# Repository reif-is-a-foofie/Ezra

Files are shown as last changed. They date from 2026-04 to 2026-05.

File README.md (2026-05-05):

# Project Ezra

**A screenless, voice-first companion phone in active industrial-design development.**

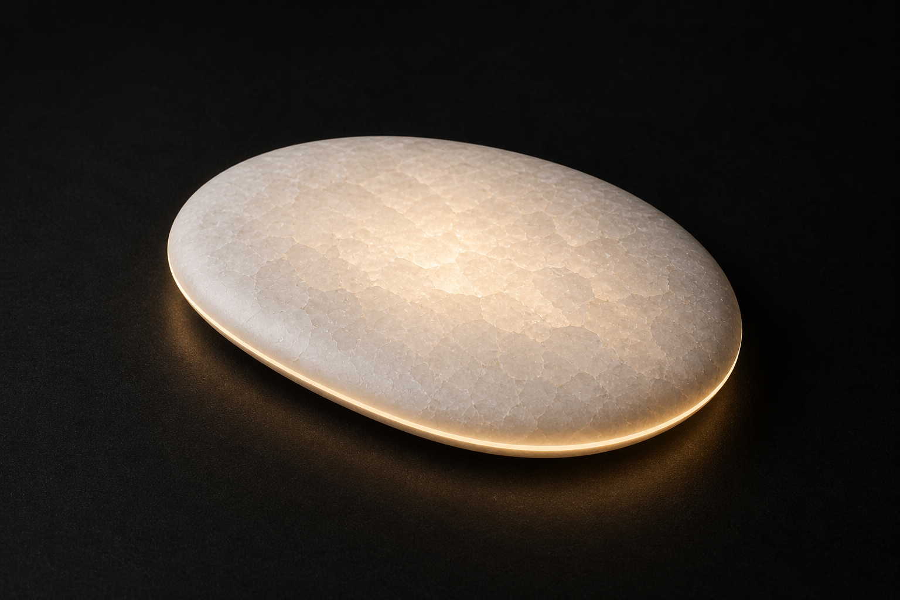
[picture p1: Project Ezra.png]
Project Ezra current render


Ezra is a pocketable AI-native communication and identity device that removes the screen entirely. It does not run apps, show feeds, or create an attention surface. It replaces the smartphone's core jobs - calls, messages, navigation, reminders, authentication, ambient awareness, and emergency utility - with voice, biometric presence, haptics, warmth, and light.

The current design direction is a warm translucent KRION/Corian mineral skip-stone form: calm from the outside, technically dense inside, and built around a clear sensor and packaging plan.

## Brought To You By The Studio

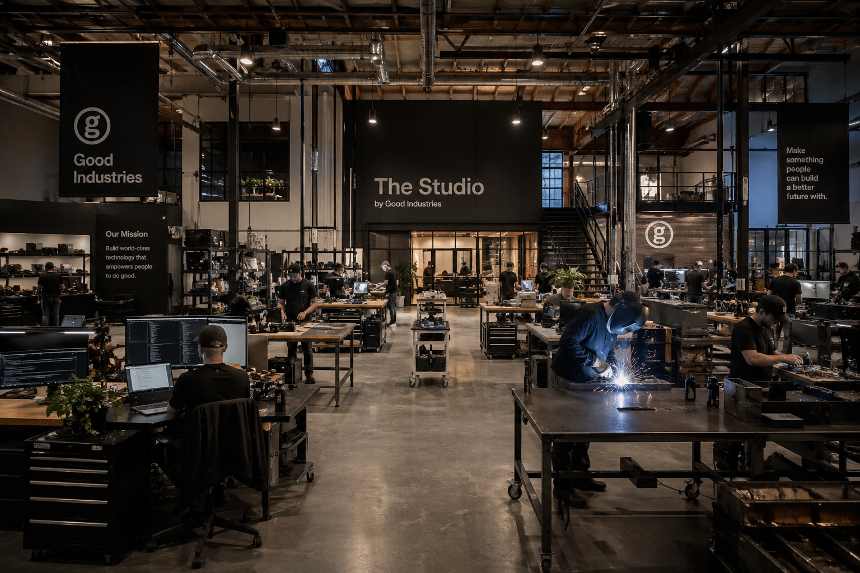
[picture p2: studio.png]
The Studio by Good Industries


Project Ezra comes from The Studio by Good Industries: the hardware, AI, and product workshop inside The Good Project. The Studio is where the concept, industrial design, Blender exploration, Onshape packaging, prototype BOM, and investor demo plan are being pulled into one buildable product direction.

## Current Design Progress

| Area | Current state | Source |
|---|---|---|
| Origin | Brought to you by The Studio, a Good Industries project inside The Good Project | [`studio.png`](studio.png) |
| Hero render | Warm crystalline mineral body with amber internal and perimeter glow | [`Project Ezra.png`](Project%20Ezra.png) |
| Phone plan | Top face, underside, internal stack, sensor map, and BOM callouts | [`project-ezra-phone-plan.svg`](project-ezra-phone-plan.svg) |
| Blender form model | Parametric skip-stone body, material system, glow target, optional feature/package guides | [`ezra_golden_phone/`](ezra_golden_phone/) |
| Blender exports | GLB checked in; OBJ/STL/MTL generated locally for CAD handoff | [`ezra_golden_phone/exports/`](ezra_golden_phone/exports/) |
| Design scenes | Morning guidance, pre-meeting calm, evening wind-down, walk prompt, emotional recovery, and bottom light platform renders | [`ezra_golden_phone/renders/`](ezra_golden_phone/renders/) |
| Onshape package | Product assembly, exploded technical assembly, part studios, and scene assemblies recorded for engineering packaging | [`ezra_golden_phone/ENGINEERING_MANIFEST.md`](ezra_golden_phone/ENGINEERING_MANIFEST.md) |
| Prototype BOM | Procurement and CAD packaging BOM with priorities, estimated pricing, and Onshape reference notes | [`ezra_golden_phone/PROTOTYPE_BUILD_PLAN.md`](ezra_golden_phone/PROTOTYPE_BUILD_PLAN.md) |
| Shape iterations | Twelve silhouette studies used to converge on the skip-stone direction | [`ezra_golden_phone/shape_iterations/`](ezra_golden_phone/shape_iterations/) |
| Earlier nautilus shell | Prior Blender/MCP shell direction and exports retained as design lineage | [`ezra_nautilus/`](ezra_nautilus/) |
| Architecture diagram | System-level hardware/software relationship map | [`system-architecture.svg`](system-architecture.svg) |
| Full spec | Product, hardware, software, identity, privacy, and mechanical packaging spec | [`SPEC.md`](SPEC.md) |
| Hardware spec | Component tables, power budget, PCB architecture, mechanical interface points | [`hardware.md`](hardware.md) |

## Main Phone Plan

Project Ezra phone plan

### Exterior Envelope

| Parameter | Current target |
|---|---:|
| Length | 116 mm |
| Width | 64 mm palm datum, 60 mm visual head taper |
| Thickness | 15 mm crowned center / 5.5 mm visual edge |
| Weight | 165 g prototype target |
| Material | Warm white KRION/Corian mineral composite |
| Form logic | Flattened nautilus / skip-stone superellipse, Lamé exponent `n = 2.5` |
| Crown point | 71.7 mm from trailing end, phi-derived |
| Exterior rule | No screen, camera, visible buttons, screw heads, app surface, or display-like notification region |

The object keeps visual symmetry while hiding tactile asymmetry: a slightly narrower head, fuller tail, thumb-side shelf, rounder finger sweep, rear-biased crown, and underside contact patch that helps orient the device in hand.

### Functional Zones

| Zone | Placement | Purpose |
|---|---|---|
| Sapphire PPG eye | Lower front / palm face | Owner authentication, pickup detection, passive regulation signals |
| Microphone array | Four-point perimeter grid | Wake word, beamforming, calls, voice interface |
| Speaker | Upper face or head edge | Voice response and calls |
| Ambient glow | 0.6 mm perimeter seam or thinned mineral edge | Quiet status, charging, contact presence, no display semantics |
| Thermal presence | Lower rear face | Warmth notification and regulation cue |
| Haptic actuator zone | Palm-biased internal chassis | Tactile language for calls, navigation, alerts, breathing cadence |
| Bottom light platform | Underside | Wide flood, focused flashlight/throw, bedside/emergency light |
| UV-A inspection | Trailing underside | Optional surface inspection demo mode |
| Qi2/MagSafe package | Hidden rear center | Wireless charging alignment without exterior ring language |
| USB-C | Bottom short edge | Prototype service and charging |
| Antenna keepout | Outer perimeter | LTE, WiFi, and Bluetooth clearance away from metal masses |

## Bill of Materials Snapshot

The full BOM is in [`ezra_golden_phone/PROTOTYPE_BUILD_PLAN.md`](ezra_golden_phone/PROTOTYPE_BUILD_PLAN.md). This is the current demo-critical subset driving the Blender and Onshape packaging pass.

| Category | Prototype component | Qty | Priority | Packaging note |
|---|---:|---:|---|---|
| Compute | Raspberry Pi CM4, 4GB RAM, 32GB eMMC, WiFi | 1 | P1 | Main processor volume |
| Compute | CM4 IO board / breakout carrier | 1 | P1 | Prototype carrier, larger than production board |
| Compute | Coral USB Accelerator / Edge TPU | 1 | P2 | Secondary AI compute and thermal allowance |
| Cellular | Quectel EC21 Mini PCIe LTE module | 1 | P1 | SIM access and RF keepout |
| Cellular | LTE adhesive flex antenna | 1 | P2 | Perimeter antenna path |
| Biometric | MAX30102 PPG / SpO2 / HR breakout | 2 | P1 | Underside optical window and isolated light path |
| Biometric | AD5940 EDA board | 1 | P2 | Conductive stress/contact sensing option |
| Biometric | Infineon SLB 9670 TPM 2.0 | 1 | P2 | PPG template and passkey key storage |
| Environmental | Sensirion SEN55 | 1 | P2 | Seam-integrated air path and membrane |
| Environmental | Bosch BMP390 | 1 | P2 | Pressure/temperature vent path |
| Haptic | DRV2605L haptic driver breakout | 2 | P1 | Waveform driver near actuator harness |
| Haptic | 10 mm coin LRA actuators | 4 | P1 | Thumb, palm, left edge, right edge zones |
| Thermal | 20 x 20 mm Peltier TEC element | 1 | P1 | Palm warmth zone with thermal spreader |
| Thermal | DRV8833 dual H-bridge | 1 | P1 | TEC driver and heat/cool control |
| Light | Cree XHP50.3 / COB primary LED | 1 | P1 | Floodlight thermal path and diffuser |
| Light | Ledil ANGIE-S TIR optic | 1 | P2 | Directional torch optic volume |
| Light | Nichia NCSU334A 365 nm UV-A LED | 2 | P1 | Shielded underside inspection emitters |
| Voice | Knowles SPH0645LM4H MEMS mic breakout | 2 | P1 | Hidden mic pores and acoustic channels |
| Voice | MAX98357A I2S amplifier + speaker | 1 | P1 | Speaker cavity and acoustic slit |
| Power | BQ25895 USB-C charger / power path board | 1 | P1 | Charger board, battery path, USB-C route |
| Power | 4000 mAh single-cell LiPo battery | 1 | P1 | Largest prototype internal mass |
| Power | USB-C breakout board | 1 | P2 | Gasketed port |
| Shell | White Corian/KRION shell stock | 1 | P2 | CNC shell and sensor drilling |

## Sensor And Subsystem Specs

### Identity

Ezra uses a MAX30102/MAX30101 PPG sensor behind a 12 mm sapphire optical window. On pickup, the device captures pulse waveform features for owner verification and session continuity. The same sensor family also supports non-medical regulation intelligence such as heart-rate trend, HRV trend, recovery signal, sympathetic arousal, circulation quality, respiratory rhythm trend, and baseline drift.

Security target: PPG template and passkey material stay on device, backed by a TPM/security element. Ezra can act as a FIDO2/WebAuthn authenticator where PPG verification supplies user verification.

### Voice And Calls

The audio stack is a four-microphone MEMS perimeter array, wake-word DSP, speech ASR, LLM/TTS response loop, MAX98357A I2S amplifier, and a 2 W speech-focused speaker. The device is designed for phone calls, voice messages, reminders, and hands-free assistance without visual UI.

### Haptic, Thermal, And Light Language

The non-screen interface uses:

| Channel | Hardware | Example behavior |
|---|---|---|
| Haptic | LRA actuators + DRV2605L | Incoming call, navigation waypoint, breath cadence, urgent alert |
| Thermal | Thin TEC or warming plate | Warmth from designated contact, regulation cue |
| Ambient glow | RGBW/amber perimeter light pipe | Quiet status, charging, presence |
| Utility light | Bottom flood/throw/flood bands | Bedside mode, emergency light, work-surface illumination |
| UV-A | Shielded 365 nm emitters | Inspection demo mode |

### Power And Packaging

The prototype BOM starts with a 4000 mAh LiPo because it is immediately buildable. The product target is a custom 5500-6500 mAh geometry under the crowned shell, with USB-C PD, hidden Qi2/MagSafe-style receiver coil, magnet ring, fuel gauge, PMIC, DC-DC rails, and perimeter antenna keepouts.

## Blender Design Package

The current Blender model is generated from [`ezra_golden_phone/scripts/build_ezra_golden_phone.py`](ezra_golden_phone/scripts/build_ezra_golden_phone.py). The script encodes the live exterior dimensions, crown offset, superellipse body, tactile asymmetry, foot placement, stone material, amber glow, bottom light platform, and optional packaging/feature guides.

Run:

```sh
blender --background --python ezra_golden_phone/scripts/build_ezra_golden_phone.py -- --save-blend --export-all --render-hero
```

Useful review flags:

```sh
--show-features
--show-packaging
```

Current checked-in/generated Blender assets:

| Asset | Purpose |
|---|---|
| [`ezra_golden_phone/ezra_golden_phone.blend`](ezra_golden_phone/ezra_golden_phone.blend) | Blender source scene |
| [`ezra_golden_phone/exports/ezra_golden_phone.glb`](ezra_golden_phone/exports/ezra_golden_phone.glb) | Portable 3D review export |
| [`ezra_golden_phone/exports/ezra_golden_phone.obj`](ezra_golden_phone/exports/ezra_golden_phone.obj) | Mesh export for CAD handoff |
| [`ezra_golden_phone/exports/ezra_golden_phone.stl`](ezra_golden_phone/exports/ezra_golden_phone.stl) | Fabrication/CAD handoff export |
| [`ezra_golden_phone/renders/hero_internal_glow.png`](ezra_golden_phone/renders/hero_internal_glow.png) | Current glow/form hero render |
| [`ezra_golden_phone/renders/bottom_light_platform.png`](ezra_golden_phone/renders/bottom_light_platform.png) | Underside light-platform review |
| [`ezra_golden_phone/renders/morning_guidance_bedside.png`](ezra_golden_phone/renders/morning_guidance_bedside.png) | Morning pickup scene |
| [`ezra_golden_phone/renders/pre_meeting_calm_haptic.png`](ezra_golden_phone/renders/pre_meeting_calm_haptic.png) | Pre-meeting regulation scene |
| [`ezra_golden_phone/renders/evening_wind_down_amber.png`](ezra_golden_phone/renders/evening_wind_down_amber.png) | Evening wind-down scene |
| [`ezra_golden_phone/renders/walk_prompt_subtle_pulse.png`](ezra_golden_phone/renders/walk_prompt_subtle_pulse.png) | Walk prompt scene |
| [`ezra_golden_phone/renders/emotional_recovery_warmth.png`](ezra_golden_phone/renders/emotional_recovery_warmth.png) | Emotional recovery scene |

### Shape Iterations

The checked-in shape studies document the path from simple oval and golden pebble through thinner, fuller, thumb-indexed, and athletic skip-stone variants. They are intentionally shape-only: no sensors, material detailing, glow, or mesh complexity. The recommended direction is the skip-stone family, with the Corian/KRION material, luminous mesh, PPG island, charger package, and scene lighting applied after silhouette selection.

See [`ezra_golden_phone/shape_iterations/README.md`](ezra_golden_phone/shape_iterations/README.md).

### Prior Nautilus Direction

[`ezra_nautilus/`](ezra_nautilus/) keeps the earlier nautilus-shell Blender direction, including the MCP addon, build script, blend source, GLB/OBJ/STL exports, and a turntable frame. It is retained as design lineage and a source of the flattened-nautilus construction logic behind the current skip-stone body.

## System Architecture

Ezra system architecture

## Onshape Engineering Package

The Onshape package is recorded in [`ezra_golden_phone/ENGINEERING_MANIFEST.md`](ezra_golden_phone/ENGINEERING_MANIFEST.md) and [`ezra_golden_phone/PROTOTYPE_BUILD_PLAN.md`](ezra_golden_phone/PROTOTYPE_BUILD_PLAN.md).

Primary document:
`Codex_Diagnostic_Test`

Current assemblies:

| Assembly | Purpose |
|---|---|
| `Ezra_Product_Assembly_v1` | Product-level packaging assembly |
| `Ezra_Exploded_Technical_Assembly_v1` | Exploded assembly for technical review |
| `Ezra_Internal_Packaging_BOM_v1` | BOM-driven internal packaging assembly |
| `Ezra_BOM_Packaging_Placeholders_v1` | Placeholder geometry and imported/vendor references |

Part Studios called out in the manifest:

| Part Studio | Purpose |
|---|---|
| `Top_Shell_A` | KRION/Corian top shell envelope, seam strategy, internal rib/standoff intent |
| `Bottom_Shell_A` | Underside, contact patch logic, sapphire PPG recess |
| `Frame_Internal_Mg` | Magnesium or glass-filled nylon internal chassis envelope |
| `Battery_Main_6000` | 82 x 45 x 9 mm pouch-envelope target |
| `PCB_Main_v1` | Main logic board, AI SoC/NPU, PMIC clusters |
| `Sensor_PPG_Module` | Secondary sensor PCB and PPG optical alignment |
| `Audio_System_Dual` | Voice speaker chamber and directional edge speaker envelope |
| `Light_System_Optics` | COB flood MCPCB and TIR flashlight lens |
| `Haptic_System_LRA` | Actuator envelope and elastomer cradle |
| `Thermal_Warmth_Module` | Graphite spreader and palm warmth zone |
| `Connectivity_Antenna_Zones` | Perimeter antenna keepout envelope |
| `Charging_USB_Qi_Module` | Hidden Qi coil, magnet ring, USB-C strategy |
| `Environmental_Sensors_Vents` | Seam-integrated vent manifold and waterproof membrane intent |

Product scene assemblies already captured for review:

| Scene | Element ID | Intent |
|---|---|---|
| `Ezra_Scene_Morning_Guidance` | `33a3eb97a8d03f4b2b933002` | Bedside pickup, soft glow, low-recovery coaching |
| `Ezra_Scene_PreMeeting_Calm` | `a2336167188af890deb331b7` | Elevated pulse while held, slow haptic breathing cadence |
| `Ezra_Scene_Evening_WindDown` | `262a42c2ed729bab77166748` | Warm amber bedside mode, sleep-window guidance |
| `Ezra_Scene_WalkPrompt` | `806f9729d9de121066534e79` | Midday sedentary pattern, subtle pulse prompt |
| `Ezra_Scene_Emotional_Recovery` | `2e2a42f345d9b77ae6e173cd` | Post-stress regulation, gentle warmth and voice guidance |

## Demo Critical Path

| Moment | Behavior | Hardware dependency |
|---|---|---|
| Hand authentication | Owner recognized from PPG pickup in roughly 4 seconds | MAX30102, TPM, enrollment model |
| Warm contact | Designated contact triggers warmth plus amber haptic pulse | LTE, LRA, TEC, light channel |
| Voice and memory | Spoken query answered from structured personal memory | CM4, mic array, speaker, LLM stack |
| UV sweep | Surface contamination fluoresces under UV-A | UV-A LEDs, filter, baffle |
| Live call | Voice command places a cellular or VoIP call | LTE, audio stack, modem software |

## Repository Map

```text
.
├── README.md
├── Project Ezra.png
├── project-ezra-phone-plan.svg
├── SPEC.md
├── hardware.md
├── firmware.md
├── haptic-language.md
├── ppg-authentication.md
├── prototype-guide.md
├── studio.png
├── system-architecture.svg
├── ezra_golden_phone/
│   ├── BRIEF.md
│   ├── ENGINEERING_MANIFEST.md
│   ├── PROTOTYPE_BUILD_PLAN.md
│   ├── ezra_golden_phone.blend
│   ├── exports/
│   ├── renders/
│   └── scripts/
└── ezra_nautilus/
    ├── BRIEF.md
    ├── ezra_nautilus.blend
    ├── exports/
    ├── renders/
    └── scripts/
```

## Status

| Track | Status |
|---|---|
| Concept and specification | Complete enough for investor/prototype package |
| Industrial design | Active: skip-stone form, glow language, underside light platform |
| Blender shell model | Active and exportable |
| Onshape packaging | Started: product assembly, exploded assembly, part studios, BOM placeholders |
| Prototype BOM | Drafted with P1/P2 priorities and procurement estimates |
| Firmware stack | Scoped |
| PPG authentication | Scoped |
| Voice stack | Scoped |
| Manufacturing partner selection | Pending |

Project Ezra is brought to you by The Studio, a project from Good Industries inside The Good Project.
[thegoodproject.net](https://thegoodproject.net)

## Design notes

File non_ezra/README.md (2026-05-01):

# Non-Ezra Support Material

This folder holds project-adjacent support material that is not part of the Ezra product specification or current skip-stone industrial design source of truth.

Current contents may include:

- `brand-kit/`: Good Industries / studio brand assets.
- `tools/`: local tool/plugin support material, including Onshape MCP references.

Ezra product work should live in root specs or the `ezra_golden_phone/` design folder.

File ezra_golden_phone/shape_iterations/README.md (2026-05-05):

# Ezra Shape Iterations

Shape-only review. No mesh, no glow, no sensors, no material detailing.

| Variant | Render | Notes |
|---|---|---|
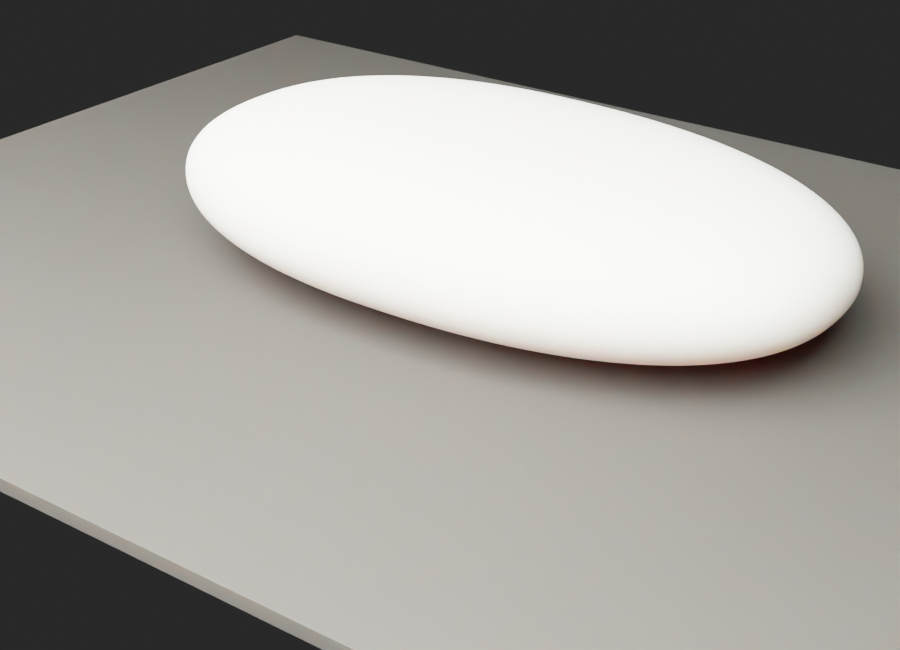
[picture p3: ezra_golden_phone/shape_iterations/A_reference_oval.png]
| A - Reference Oval |  | Closest to the hand stone: simple oval, felt asymmetry, least gadget-like. |
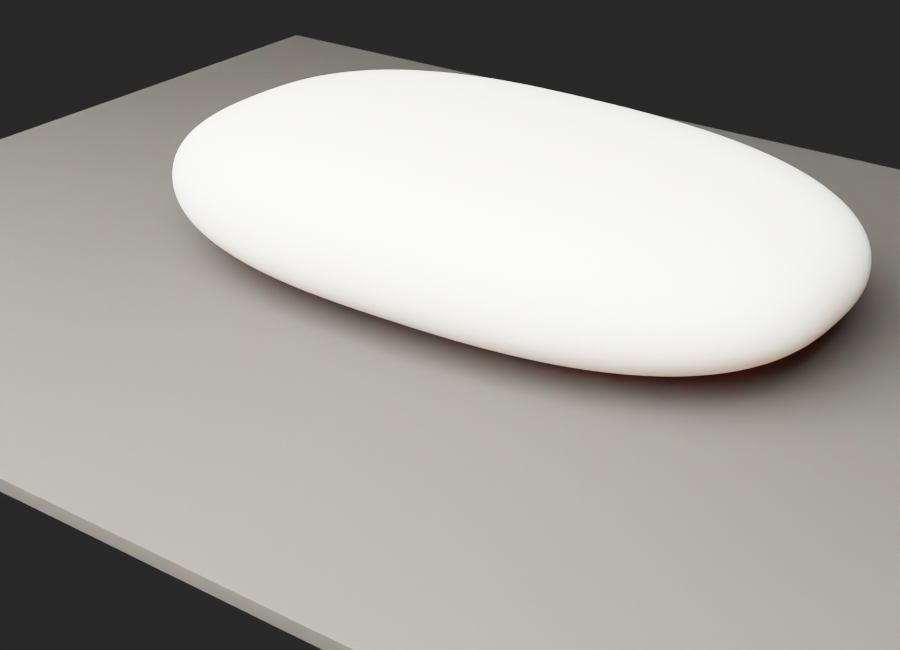
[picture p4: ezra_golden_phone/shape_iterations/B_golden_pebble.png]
| B - Golden Pebble |  | Current spec translated into a more natural pebble, still phone/pocket scaled. |
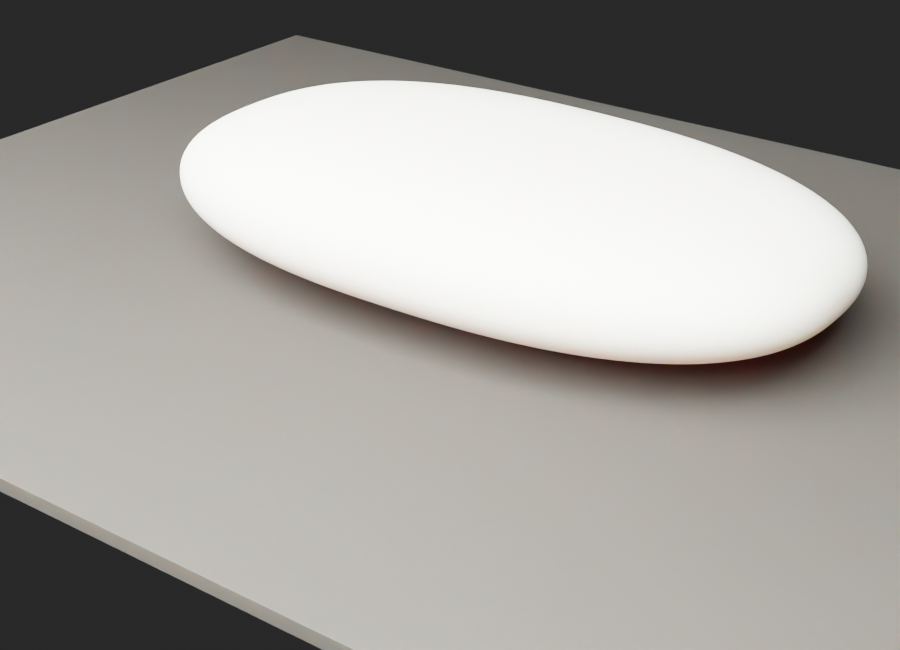
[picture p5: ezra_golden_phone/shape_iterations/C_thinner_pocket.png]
| C - Thinner Pocket |  | More pocketable and less object-heavy; may lose heirloom density. |
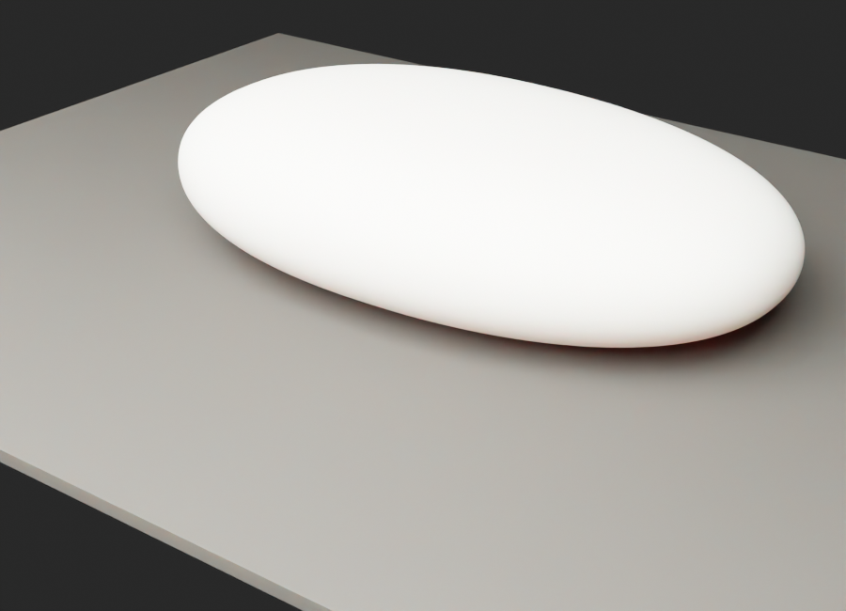
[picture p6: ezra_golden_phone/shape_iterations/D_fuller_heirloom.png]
| D - Fuller Heirloom |  | Most stone-like mass and warmth; strongest hand presence. |
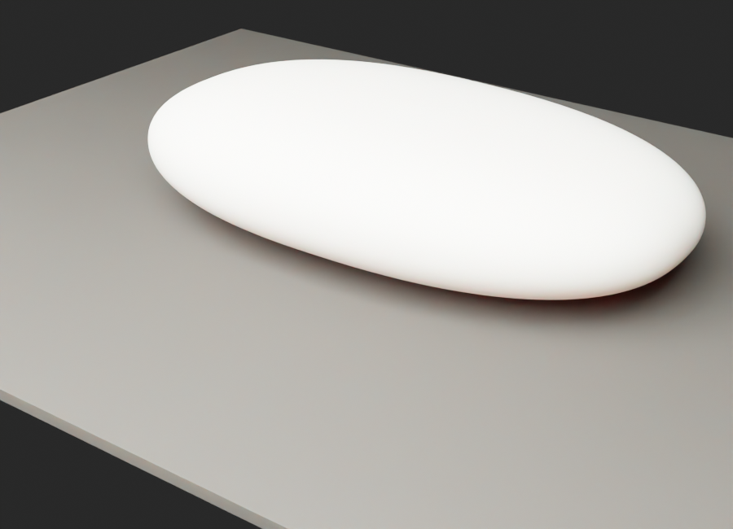
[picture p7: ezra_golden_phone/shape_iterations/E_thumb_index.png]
| E - Thumb Index |  | Same visual calm, stronger one-side flattening for pocket orientation. |
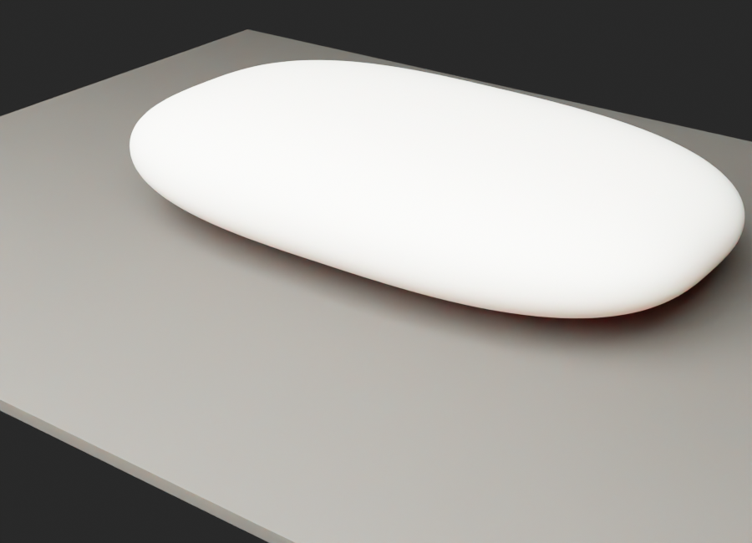
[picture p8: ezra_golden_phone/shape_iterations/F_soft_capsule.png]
| F - Soft Capsule |  | More phone-compatible silhouette; safer for chargers but less natural. |
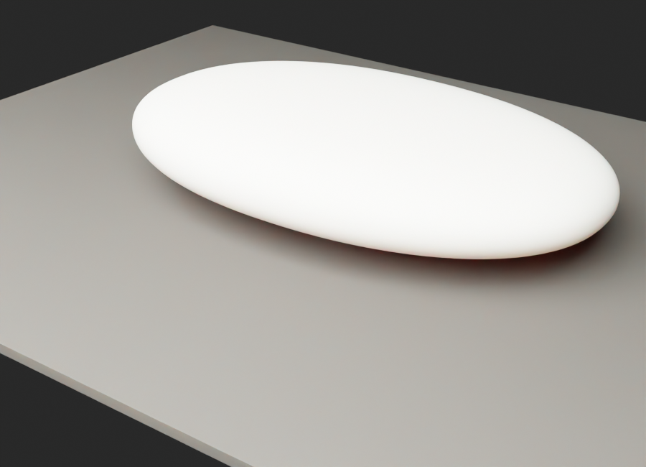
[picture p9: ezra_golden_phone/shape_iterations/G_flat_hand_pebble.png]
| G - Flat Hand Pebble |  | Closest to the grey reference: broad horizontal palm stone, low dome, soft lens edge. |
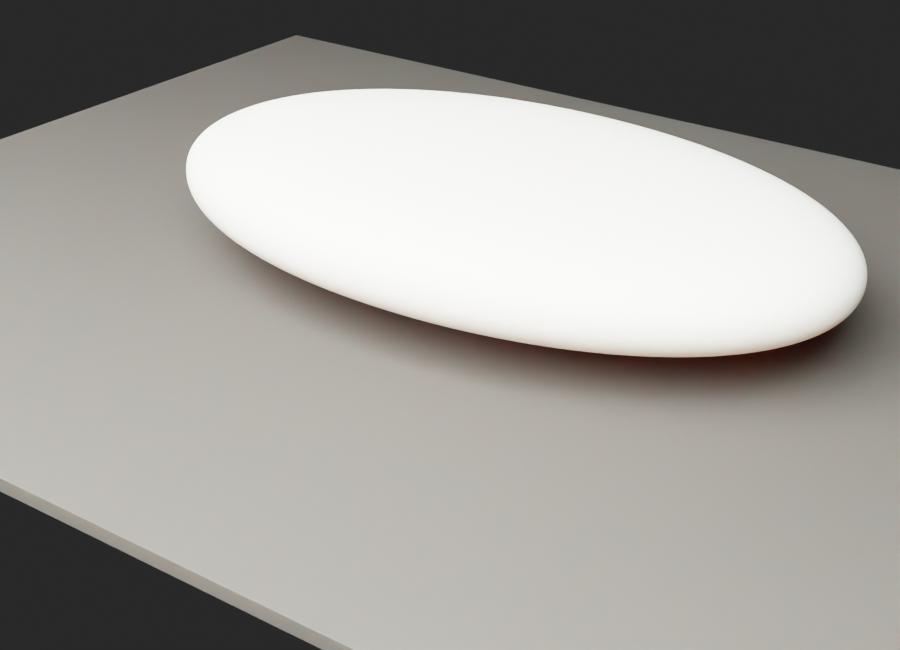
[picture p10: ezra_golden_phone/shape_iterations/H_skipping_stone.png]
| H - Skipping Stone |  | Thinnest and calmest; very pocketable, but internal packaging becomes harder. |
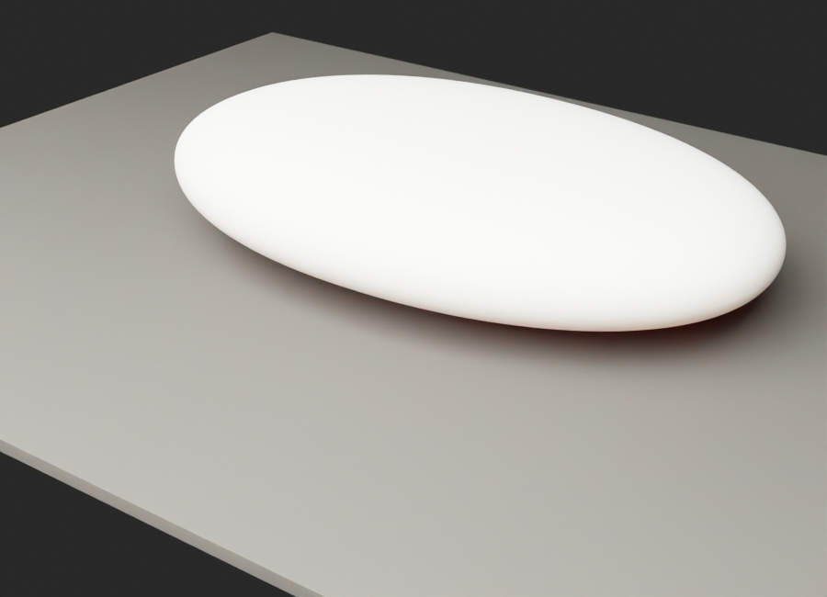
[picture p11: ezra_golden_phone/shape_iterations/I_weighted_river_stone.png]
| I - Weighted River Stone |  | Reference-like broad face with more belly for battery and hand warmth. |
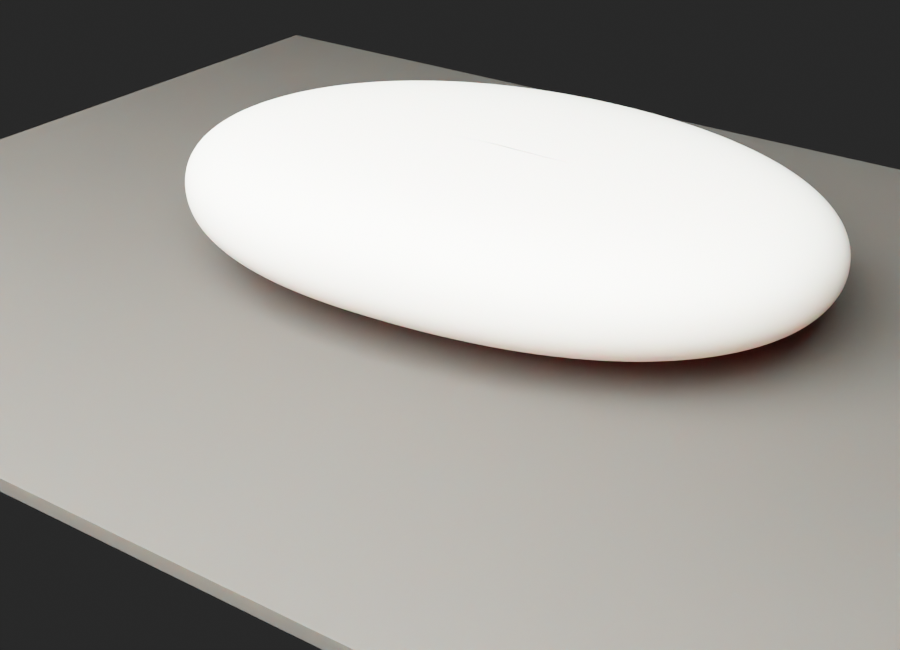
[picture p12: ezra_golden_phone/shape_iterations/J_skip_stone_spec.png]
| J - Skip Stone Spec |  | Direct translation of the new brief: 103 x 75 x 17.5 mm, broad and thin with lens taper. |
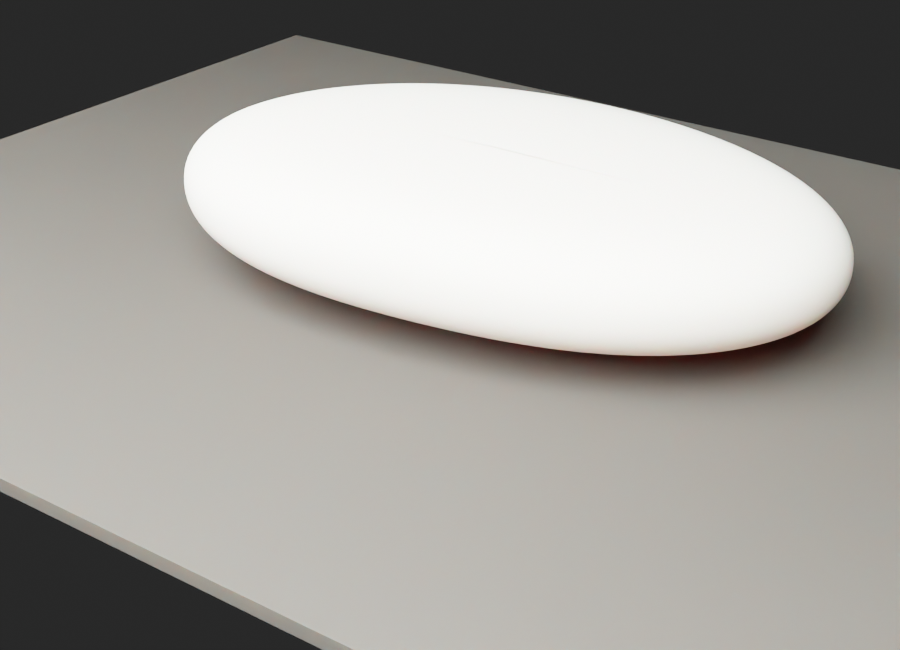
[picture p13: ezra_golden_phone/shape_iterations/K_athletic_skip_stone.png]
| K - Athletic Skip Stone |  | Faster leading end and stronger diagonal energy; more capable/tool-like. |
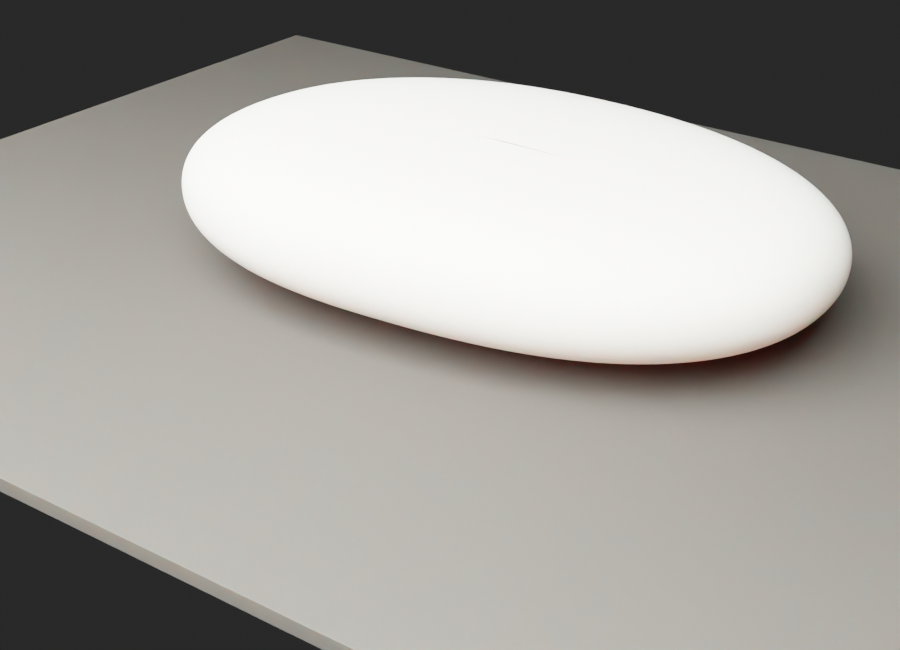
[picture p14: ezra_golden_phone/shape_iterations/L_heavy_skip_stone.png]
| L - Heavy Skip Stone |  | Keeps the skip-stone plan but restores internal volume for battery/speakers. |

Recommendation: choose silhouette first, then apply Corian/KRION material, luminous mesh, PPG island, charger packaging, and scene lighting to one selected direction.

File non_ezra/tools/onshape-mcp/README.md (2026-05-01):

# Onshape MCP Server

Enhanced Model Context Protocol (MCP) server for programmatic CAD modeling with Onshape.

## Features

This MCP server provides comprehensive programmatic access to Onshape's REST API, enabling:

### Core Capabilities (45 tools)

- **Document Discovery** - Search and list projects, find Part Studios, navigate workspaces
- **Parametric Sketches** - Rectangles, circles, lines, and arcs on standard planes
- **Feature Management** - Extrude, revolve, thicken, fillet, chamfer, boolean, and pattern features
- **Assembly Management** - Create assemblies, add instances, position parts, create mates (fastened, slider, revolute, cylindrical)
- **Assembly Analysis** - Interference checking, position verification, face coordinate systems, body details
- **Variable Tables** - Read and write Onshape variable tables for parametric designs
- **FeatureScript** - Evaluate FeatureScript expressions, get bounding boxes
- **Export** - Export Part Studios and Assemblies to STL, STEP, PARASOLID, GLTF, OBJ
- **Part Studio Management** - Create and manage Part Studios programmatically

## Installation

### Prerequisites

- Python 3.10 or higher
- Onshape account with API access
- Onshape API keys (access key and secret key)

### Setup

1. Clone the repository:
```bash
git clone https://github.com/hedless/onshape-mcp.git
cd onshape-mcp
```

2. Create a virtual environment:
```bash
python -m venv venv
source venv/bin/activate  # On Windows: venv\Scripts\activate
```

3. Install dependencies:
```bash
pip install -e .
```

4. Set up environment variables:
```bash
export ONSHAPE_ACCESS_KEY="your_access_key"
export ONSHAPE_SECRET_KEY="your_secret_key"
```

Or create a `.env` file:
```
ONSHAPE_ACCESS_KEY=your_access_key
ONSHAPE_SECRET_KEY=your_secret_key
```

## Getting Onshape API Keys

1. Go to [Onshape Developer Portal](https://dev-portal.onshape.com/)
2. Sign in with your Onshape account
3. Create a new API key
4. Copy the Access Key and Secret Key

## Usage

### Running the Server

```bash
onshape-mcp
```

Or directly with Python:
```bash
python -m onshape_mcp.server
```

### Configuring with Claude Code

Add to your `~/.claude/mcp.json`:

```json
{
  "mcpServers": {
    "onshape": {
      "command": "/absolute/path/to/onshape-mcp/venv/bin/python",
      "args": ["-m", "onshape_mcp.server"],
      "env": {
        "ONSHAPE_ACCESS_KEY": "your_access_key_here",
        "ONSHAPE_SECRET_KEY": "your_secret_key_here"
      }
    }
  }
}
```

**Important Notes:**
- Use the **absolute path** to your virtual environment's Python executable
- Find your path: `cd onshape-mcp && pwd` to get the directory path
- On Windows: Use `C:/path/to/onshape-mcp/venv/Scripts/python.exe`
- Replace the API keys with your actual keys from [Onshape Developer Portal](https://dev-portal.onshape.com/)
- **Restart Claude Code** after editing `mcp.json`

**Verify it works:**
Ask Claude Code: "Can you list my Onshape documents?"

For complete setup instructions, see [docs/QUICK_START.md](docs/QUICK_START.md).

## Available Tools

### Document & Navigation Tools

| Tool | Description |
|---|---|
| `list_documents` | List documents with filtering and sorting |
| `search_documents` | Search documents by name or description |
| `get_document` | Get detailed document information |
| `get_document_summary` | Get comprehensive summary with workspaces and elements |
| `find_part_studios` | Find Part Studios with optional name filtering |
| `get_elements` | Get all elements (Part Studios, Assemblies, BOMs) in a workspace |
| `get_parts` | Get all parts from a Part Studio |
| `create_document` | Create a new Onshape document |
| `create_part_studio` | Create a new Part Studio in a document |

### Assembly Tools

| Tool | Description |
|---|---|
| `create_assembly` | Create a new Assembly in a document |
| `add_assembly_instance` | Add a part or sub-assembly instance to an assembly |
| `get_assembly` | Get assembly structure with instances and occurrences |
| `transform_instance` | Apply a relative transform (inches/degrees). Fails on fixed instances. |
| `set_instance_position` | Set absolute position (resets rotation). Fails on fixed instances. |
| `align_instance_to_face` | Align one instance flush against a face of another |
| `create_mate_connector` | Create an explicit mate connector on a face with offsets |
| `create_fastened_mate` | Create a rigid (fastened) mate between two instances |
| `create_slider_mate` | Create a linear motion mate. First instance slides relative to second. |
| `create_revolute_mate` | Create a rotational mate. First instance rotates relative to second. |
| `create_cylindrical_mate` | Create a slide+rotate mate. First instance moves relative to second. |
| `delete_feature` | Delete a feature (mate, mate connector, etc.) from an assembly or Part Studio |

### Assembly Analysis Tools

| Tool | Description |
|---|---|
| `get_assembly_positions` | Get positions, sizes, and bounds of all instances (in inches) |
| `get_assembly_features` | Get all features with their state (OK/ERROR/SUPPRESSED) |
| `get_body_details` | Get face IDs, surface types, normals, and origins for all parts |
| `get_face_coordinate_system` | Query the outward-facing coordinate system for a specific face |
| `check_assembly_interference` | Check for overlapping/interfering parts using bounding box detection |

### Sketch Tools

| Tool | Description |
|---|---|
| `create_sketch_rectangle` | Rectangle with optional variable references for width/height |
| `create_sketch_circle` | Circle with center point and radius |
| `create_sketch_line` | Line from start point to end point |
| `create_sketch_arc` | Arc with center, radius, start angle, and end angle |

All sketch tools support `plane` (Front/Top/Right) and `name` parameters. Dimensions are in inches.

### Feature Tools

| Tool | Description |
|---|---|
| `create_extrude` | Extrude a sketch with depth, optional variable reference, and operation type |
| `create_thicken` | Thicken a sketch into a solid with optional midplane/opposite direction |
| `create_revolve` | Revolve a sketch around an axis (X/Y/Z) with angle and operation type |
| `create_fillet` | Round edges by edge IDs with radius (supports variable references) |
| `create_chamfer` | Bevel edges by edge IDs with distance (supports variable references) |
| `create_linear_pattern` | Repeat features along an axis (X/Y/Z) with distance and count |
| `create_circular_pattern` | Repeat features around an axis with count and angle spread |
| `create_boolean` | Union, subtract, or intersect bodies by deterministic IDs |

### Variable & Feature Tools

| Tool | Description |
|---|---|
| `get_variables` | Get all variables from a Part Studio variable table |
| `set_variable` | Set or update a variable (e.g., `"0.75 in"`) |
| `get_features` | Get all features from a Part Studio |

### FeatureScript Tools

| Tool | Description |
|---|---|
| `eval_featurescript` | Evaluate a FeatureScript lambda expression (read-only) |
| `get_bounding_box` | Get the tight bounding box of all parts in a Part Studio |

### Export Tools

| Tool | Description |
|---|---|
| `export_part_studio` | Export to STL, STEP, PARASOLID, GLTF, or OBJ (optional `partId` filter) |
| `export_assembly` | Export to STL, STEP, or GLTF |

## Architecture

```
onshape_mcp/
├── api/
│   ├── client.py         # HTTP client with HMAC authentication
│   ├── documents.py      # Document discovery & navigation
│   ├── partstudio.py     # Part Studio management
│   ├── variables.py      # Variable table management
│   ├── assemblies.py     # Assembly lifecycle, mates & features
│   ├── export.py         # Part Studio & Assembly export
│   └── featurescript.py  # FeatureScript evaluation
├── builders/
│   ├── sketch.py         # Sketch builder (rectangle, circle, line, arc, polygon)
│   ├── extrude.py        # Extrude feature builder
│   ├── revolve.py        # Revolve feature builder
│   ├── fillet.py         # Fillet feature builder
│   ├── chamfer.py        # Chamfer feature builder
│   ├── boolean.py        # Boolean operations (union, subtract, intersect)
│   ├── pattern.py        # Linear & circular pattern builders
│   ├── mate.py           # Mate connector & mate builders (face-based)
│   └── thicken.py        # Thicken feature builder
├── analysis/
│   ├── interference.py   # Bounding-box interference detection
│   ├── positioning.py    # Instance position queries & alignment
│   └── face_cs.py        # Face coordinate system queries
├── tools/
│   └── __init__.py       # MCP tool definitions
└── server.py             # Main MCP server (45 tools)
```

## Examples

### Example 1: Finding and Working on a Project

```python
# Search for your project
documents = await search_documents(query="robot arm", limit=5)

# Get the first matching document
doc_id = documents[0].id

# Get comprehensive summary
summary = await get_document_summary(doc_id)

# Find Part Studios in main workspace
workspace_id = summary['workspaces'][0].id
part_studios = await find_part_studios(doc_id, workspace_id, namePattern="base")

# Now work with the Part Studio
elem_id = part_studios[0].id
```

### Example 2: Creating a Parametric Cabinet

```python
# Set variables
await set_variable(doc_id, ws_id, elem_id, "width", "39.5 in")
await set_variable(doc_id, ws_id, elem_id, "depth", "16 in")
await set_variable(doc_id, ws_id, elem_id, "height", "67.125 in")
await set_variable(doc_id, ws_id, elem_id, "wall_thickness", "0.75 in")

# Create side panel sketch
await create_sketch_rectangle(
    doc_id, ws_id, elem_id,
    name="Side Panel",
    plane="Front",
    corner1=[0, 0],
    corner2=[16, 67.125],
    variableWidth="depth",
    variableHeight="height"
)

# Extrude to create side
await create_extrude(
    doc_id, ws_id, elem_id,
    name="Side Extrude",
    sketchFeatureId="<sketch_id>",
    depth=0.75,
    variableDepth="wall_thickness"
)
```

## Development

### Running Tests

The project has comprehensive test coverage with **471 unit tests**.

```bash
# Run all tests
pytest

# Run with coverage
pytest --cov

# Run specific module tests
pytest tests/api/test_documents.py -v

# Use make commands
make test
make test-cov
make coverage-html
```

For detailed testing documentation, see [docs/TESTING.md](docs/TESTING.md).

### Code Formatting

```bash
ruff format .
ruff check .
```

## Documentation

### Getting Started
- **[docs/QUICK_START.md](docs/QUICK_START.md)** - Quick start guide for Claude Code users
- **[docs/DEV_SETUP.md](docs/DEV_SETUP.md)** - Development environment setup with SSE mode and debugging

### Development & Testing
- **[docs/TESTING.md](docs/TESTING.md)** - Testing guide and best practices
- **[docs/TEST_SUMMARY.md](docs/TEST_SUMMARY.md)** - Test suite overview
- **[docs/FEATURE_SUMMARY.md](docs/FEATURE_SUMMARY.md)** - Implementation details and statistics

### API & Implementation
- **[docs/ONSHAPE_API_IMPROVEMENTS.md](docs/ONSHAPE_API_IMPROVEMENTS.md)** - API format fixes and BTMSketch-151 implementation
- **[docs/SKETCH_PLANE_REFERENCE_GUIDE.md](docs/SKETCH_PLANE_REFERENCE_GUIDE.md)** - Advanced: Geometry-referenced sketch planes
- **[docs/NEXT_STEPS_GEOMETRY_REFERENCES.md](docs/NEXT_STEPS_GEOMETRY_REFERENCES.md)** - Roadmap for geometry reference implementation
- **[docs/DOCUMENT_DISCOVERY.md](docs/DOCUMENT_DISCOVERY.md)** - Complete guide to document discovery features
- **[docs/PARTS_ASSEMBLY_TOOLS.md](docs/PARTS_ASSEMBLY_TOOLS.md)** - Parts and assembly tool documentation

### Project Analysis & Research
- **[docs/CARPENTRY_PRINCIPLES_FOR_CAD.md](docs/CARPENTRY_PRINCIPLES_FOR_CAD.md)** - How to think like a carpenter in CAD
- **[docs/LEARNING_SUMMARY.md](docs/LEARNING_SUMMARY.md)** - Summary of side panel analysis and learnings
- **[docs/DISPLAY_CABINETS_ANALYSIS_SUMMARY.md](docs/DISPLAY_CABINETS_ANALYSIS_SUMMARY.md)** - Analysis of display cabinets project
- **[docs/AGENT_CREATION_GUIDE.md](docs/AGENT_CREATION_GUIDE.md)** - Guide for creating CAD agents
- **[docs/CREATING_CAD_EXPERT_AGENT.md](docs/CREATING_CAD_EXPERT_AGENT.md)** - Creating specialized CAD expert agents

### Knowledge Base & Examples

- **[knowledge_base/assembly_workflow_guide.md](knowledge_base/assembly_workflow_guide.md)** - Comprehensive assembly methodology (positioning, mates, solver behavior)
- **[examples/cabinet_assembly.md](examples/cabinet_assembly.md)** - Complete worked example: cabinet with sliding drawers
- **[knowledge_base/](knowledge_base/)** - Onshape feature examples and research

## Roadmap

### Current Status

- Document discovery and navigation (10 tools)
- Sketch creation with rectangles, circles, lines, and arcs
- Feature tools: extrude, revolve, thicken, fillet, chamfer, boolean, patterns
- Full assembly management: fastened, slider, revolute, and cylindrical mates with face-based mate connectors
- Assembly analysis: interference checking, position verification, face coordinate systems
- Variable table management
- FeatureScript evaluation and bounding box queries
- Export to STL, STEP, PARASOLID, GLTF, OBJ
- 471 comprehensive unit tests
- Live-tested on multi-part assemblies (25-instance cabinet with 66 features)

### In Research

- **Geometry-referenced sketch planes** - Create sketches on faces from existing features (see [docs/SKETCH_PLANE_REFERENCE_GUIDE.md](docs/SKETCH_PLANE_REFERENCE_GUIDE.md))
- Query API investigation - How to programmatically reference geometry
- Entity ID mapping - Understanding Onshape's internal ID system

### Near-Term Priorities

- [ ] Implement `create_sketch_on_geometry()` for carpentry-correct cabinet assembly
- [ ] Sketch constraints (coincident, parallel, tangent, etc.)
- [ ] Pocket cuts and profiles for joinery (dados, rabbets)

### Long-Term Goals

- [ ] Drawing creation
- [ ] Bill of Materials (BOM) generation
- [ ] Advanced constraints and relations
- [ ] Configuration parameter support

### Woodworking-Specific Features

- [ ] Joinery library (dado, rabbet, mortise & tenon, dovetail)
- [ ] Standard hardware patterns (shelf pins, drawer slides)
- [ ] Cut list generation
- [ ] Material optimization (sheet layout)
- [ ] Assembly instructions generation

## Contributing

Contributions are welcome! Please feel free to submit a Pull Request.

## License

MIT License

## Acknowledgments

- Inspired by [OnPy](https://github.com/kyle-tennison/onpy)
- Built on the [Model Context Protocol](https://modelcontextprotocol.io/)
- Onshape API documentation: https://onshape-public.github.io/docs/

## Support

For issues and questions:
- GitHub Issues: https://github.com/hedless/onshape-mcp/issues
- Onshape API Forum: https://forum.onshape.com/

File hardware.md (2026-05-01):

# Ezra — Hardware Specification

**Version:** 0.3  
**Stage:** Pre-prototype (Investor Demo Build)

---

## Component Selection Table

### Compute

| Component | Part | Manufacturer | Notes |
|---|---|---|---|
| System on Chip | CM4 (4GB RAM / 32GB eMMC) | Raspberry Pi Foundation | Prototype only; production target: custom ARM SoC |
| Security Element | SLB 9670 TPM 2.0 | Infineon | PPG template and FIDO2 key storage |
| I/O Expander | MCP23017 | Microchip | GPIO expansion for button inputs and LED control |

### Cellular & Wireless

| Component | Part | Manufacturer | Notes |
|---|---|---|---|
| LTE Modem | EC25-A Mini PCIe | Quectel | Cat 4 LTE, North America bands |
| Antenna | FXP73 flex LTE | Taoglas | Embedded in chassis perimeter |
| WiFi / Bluetooth | Integrated | RPi Foundation | CM4 onboard 802.11ac + BT 5.0 |
| SIM Slot | Nano SIM + eSIM | — | Dual SIM support |

### Audio

| Component | Part | Manufacturer | Interface | Notes |
|---|---|---|---|---|
| Speaker | GF0401 (2W, 4Ω, 40mm) | Dayton Audio | Analog | Tuned for 200Hz–8kHz voice |
| Amplifier | MAX98357A | Maxim | I2S | 3.2W Class D, filterless |
| MEMS Mic (×4) | SPH0645LM4H | Knowles | I2S | Golden-rectangle perimeter array, phi-derived spacing |
| DSP / Wake Word | TrulyHandsfree SDK | Sensory | SPI | Wake word "Ezra," always-on < 10mW |

### Biometric / Identity

| Component | Part | Manufacturer | Interface | Notes |
|---|---|---|---|---|
| PPG Sensor | MAX30102 | Maxim/Analog Devices | I2C | Red 660nm + IR 880nm |
| Optical Window | Sapphire disc, 12mm × 1.5mm | Industrial optics supplier | — | < 2% loss at sensor wavelengths |
| Optical Adhesive | NOA61 UV adhesive | Norland | — | Window to sensor bonding |

### Passive Regulation Signals

The PPG subsystem is a continuous relationship sensor, not just an unlock mechanism. It should sample opportunistically on pickup and during natural palm contact, then feed local trend models for heart rate, HRV, recovery state, stress-load trend, sympathetic arousal, cold-hand/circulation state, respiratory rhythm trend, and baseline drift. This is product guidance data, not diagnostic data.

Regulatory constraint: do not claim medical diagnosis, disease detection, treatment, or clinical accuracy unless Ezra enters a formal regulated medical pathway. Default positioning is pattern intelligence and personal regulation.

### Haptic

| Component | Part | Manufacturer | Interface | Notes |
|---|---|---|---|---|
| Actuator | L5 LRA | Lofelt | — | ±3g peak force, 50–300Hz |
| Driver | DRV2605L | Texas Instruments | I2C | Arbitrary waveform RAM |
| Isolation | Sorbothane 40 duro | Sorbothane | — | Actuator mount isolation |

### Thermal (Warmth)

| Component | Part | Manufacturer | Notes |
|---|---|---|---|
| Thermoelectric element | Thin thermal module / resistive warming plate | TBD | Production target for 21mm crowned body with 8mm edge thickness |
| Demo Peltier Element | TEC1-12706 | Generic | 40×40mm, 6A max, 51W; benchtop/investor demo only |
| MOSFET Driver | IRL3803 | Vishay | PWM control via CM4 GPIO |
| Heat Spreader | 1mm copper sheet, 50×40mm | McMaster-Carr | Hot side to chassis mass |
| Thermal Interface | Fujipoly XR-m (3 W/mK) | Fujipoly | Element to spreader |

### Illumination

| Component | Part | Manufacturer | Notes |
|---|---|---|---|
| COB LED Array | BXRE-27G1000-C-73 (1,200 lm) | Bridgelux | Main flood/beam element |
| TIR Optic | TIR-T-H-10 (10° beam) | LEDiL | 60m beam throw |
| LED Driver | AL8861 | Diodes Inc. | Constant current, PWM dimming |
| Ambient Ring | SK6812 RGBW, 5mm, ×8 | Worldsemi | Notification color language |

### Power

| Component | Part | Manufacturer | Notes |
|---|---|---|---|
| Battery | Custom Li-ion pouch, target 5,500–6,500mAh equivalent geometry | TBD | Largest central internal component; conformal or stacked pouch layout under crowned shell |
| Charging IC | BQ25895 | Texas Instruments | USB-C PD, 18W input |
| Wireless charging receiver | Qi2/MagSafe-compatible receiver module | TBD | Hidden centered rear coil; validate certification path with WPC |
| Magnetic alignment ring | N52 magnet ring array | TBD | Hidden under rear shell, sized for common phone magnetic charger puck alignment |
| USB-C Connector | HRO TYPE-C-31-M-17 | HRO | IP54 rated |
| Fuel Gauge | MAX17048 | Maxim | 1% accuracy SoC estimation |
| DC-DC (5V rail) | TPS62133 | Texas Instruments | CM4 power supply |
| DC-DC (3.3V rail) | AP2112K-3.3 | Diodes Inc. | Sensor power rail |

---

## Power Budget (Estimated)

| Subsystem | Active (mA @ 3.7V) | Standby (mA) |
|---|---|---|
| CM4 (idle) | 400 | 80 |
| CM4 (voice processing) | 900 | — |
| LTE Modem (connected) | 350 | 15 |
| Audio (playback) | 180 | 2 |
| PPG sensor (active) | 5 | 0.7 |
| LRA (active) | 200 | 0 |
| Peltier (active, 50% PWM) | 3,000 | 0 |
| COB LED (max) | 1,000 | 0 |
| Misc (MCUs, sensors) | 30 | 8 |

**Typical use (voice + calls, no warmth/LED):** ~1,800mA average → 6,000mAh / 1,800mA ≈ ~3.3 hours of active-heavy use  
**Standby (LTE connected, PPG monitoring):** ~110mA → 6,000mAh / 110mA ≈ ~54 hours

---

## Thermal Constraints

The benchtop TEC1-12706 draws up to 22W (6A × 3.7V) at full duty cycle and is too bulky for the phone-scale enclosure. Production hardware needs a thin thermal module or resistive warming plate sized for burst warmth notifications (3–10 seconds), coupled to the palm-side shell through a graphite spreader. The chassis and mineral shell act as thermal reservoirs.

**Design constraint:** Limit Peltier duty cycle to 30-second maximum per activation. Software-enforced cooldown of 60 seconds between activations to prevent thermal accumulation.

---

## PCB Architecture

The device uses three PCBs:

1. **Main board:** CM4 carrier, LTE modem, power management, USB-C, battery connectors
2. **Sensor board:** MAX30102, DRV2605L, MCP23017, MAX17048, ambient LED ring
3. **Audio board:** MEMS mic array, MAX98357A, speaker connector

Boards connect via FFC (flat flexible cable) with ZIF connectors. This allows sensor and audio boards to be positioned independently of the main board geometry.

---

## Mechanical Interface Points

| Feature | Location | Tolerance |
|---|---|---|
| Speaker aperture | Upper face center | ±0.3mm |
| Sensor window | Lower face center | ±0.1mm (optical alignment critical) |
| Qi receiver coil | Rear center, hidden behind shell | ±0.5mm |
| Magnetic alignment ring | Rear center around coil, hidden behind shell | ±0.5mm |
| USB-C port | Lower edge | ±0.2mm |
| Internal glow / ambient light pipe | Perimeter groove or thinned mineral window | ±0.5mm |
| Peltier contact zone | Lower rear face | ±1mm |
| Battery access (service) | None (sealed) | — |

## Mechanical Envelope

| Parameter | Target |
|---|---|
| Length | 108mm |
| Tail width | 66mm |
| Head width | 63mm |
| Center thickness | 21mm |
| Edge thickness | 8mm |
| Top shell wall | 3.2mm |
| Bottom shell wall | 2.8mm |
| Mass target | 210g |

The exterior must carry subtle tactile asymmetry: narrower head for flashlight/directional speaker/mic orientation, fuller tail for battery and biometric mass, a shallower thumb-side sweep, rounder finger-side squeeze contour, rearward crown offset of roughly 5mm, and a biased underside contact patch. The asymmetry should be felt more than seen.

---

*Hardware spec current as of April 2026. Prototype build may substitute components based on availability.*

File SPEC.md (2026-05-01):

# Ezra — Full Product Specification

**Version:** 0.4 (Pre-prototype)  
**Status:** Specification phase  
**Owner:** Good Industries / The Good Project

---

## 1. Physical Form Factor

### 1.1 Dimensions & Weight

| Parameter | Target |
|---|---|
| Length | 116 mm |
| Width | 64 mm palm datum, with subtly narrower leading/head end |
| Depth | 15 mm crowned center / 5.5 mm visual edge |
| Top shell wall | TBD after shell split; target 3.0-3.5 mm |
| Bottom shell wall | 2.5 mm at light-diffusion zones / 3.5 mm perimeter target |
| Weight | 165g prototype target |
| Form | Flattened nautilus / skip-stone profile with hidden tactile asymmetry |

The governing palm datum is the 64mm short axis. The current skip-stone body is 116mm long, giving A/B = 1.8125. This is intentionally longer than pure φ because the device needs pocket reach, bottom flood-light real estate, and a more athletic skipping-stone read. The form remains φ-influenced through crown placement, foot geometry, haptic placement, seam behavior, and construction logic.

The industrial design target is a translucent warm-white mineral skip stone: longer and thinner than expected, shallow crowned top face, aggressively tapered edges, and no visible screen, camera, buttons, screws, or top markings. The object should feel like a flattened nautilus shell worn into a river stone, not a phone slab or hockey puck.

Ezra uses tactile asymmetry hidden inside visual symmetry. The leading/head end is slightly narrower and faster. The trailing/tail end is calmer and slightly fuller. The right-hand thumb side has a subtle concavity/shelf, while the opposite side remains a smooth finger sweep. The crown peak is φ-derived at 71.7mm from the trailing end, 13.7mm ahead of true center.

Sacred-geometry construction rules:
- **φ:** 1.6180339887.
- **Palm datum:** B = 64mm.
- **Long axis:** A = 116mm.
- **Superellipse:** Lamé curve, n = 2.5.
- **Crown point:** A/φ = 71.7mm from trailing end.
- **Feet:** golden gnomon triangle at (43, 0), (-20, -20), (-20, +20) mm.
- **Foot triangle:** 40mm base, 66.1mm legs, apex angle 35.2°, visually approximating the 36°/72°/72° golden gnomon.
- **Fibonacci spiral:** construction guide only. The top should feel derived from a flattened nautilus spiral, but the spiral must not be lit, engraved, printed, or visible as graphics.

The weight is deliberate but no longer brick-like. The target is 165g: dense enough to feel premium and stable on its feet, light enough to pocket and handle as a personal object.

### 1.2 Material: KRION Mineral Solid Surface

KRION (manufactured by Porcelanosa Group) is a mineral composite of approximately 2/3 natural minerals (primarily aluminum trihydrate) bound by a high-performance acrylic resin. Properties relevant to Ezra:

- **Non-porous:** Does not harbor bacteria; hygienic for daily skin contact
- **Thermoformable:** Can be CNC milled and hand-finished to tight tolerances
- **Repairable:** Surface scratches can be sanded and re-polished
- **Thermal conductivity:** Moderate; works with rather than against the Peltier element
- **Available in matte white and mineral tones:** Consistent with the product's aesthetic language

Alternative: Corian (DuPont / Trinseo) is functionally similar and more widely available through fabricators in the US market.

### 1.2.1 Internal Glow

Ezra may use a low-output internal amber glow through thinned KRION/Corian or a hidden perimeter light pipe. This is not a display surface and must not resolve into icons, pixels, notification badges, or text. The glow is limited to ambient state, warmth/social presence, charging feedback, and quiet location/state signaling. Translucency must be validated against actual material samples because standard mineral solid surface is mostly opaque at normal wall thickness.

Visual target reference, May 2026: a warm translucent mineral pebble on a black surface, with a crystalline/alabaster Corian texture, softly glowing amber core, and a clean continuous amber perimeter seam. The edge glow should reflect subtly on the table. The top face remains visually pure: no Fibonacci line, no logo, no lens, no display, no obvious sensor, and no decorative mesh. The surface should read as natural crystalline mineral, like white onyx/alabaster/Corian, not plastic.

### 1.3 Sensor Window

A 12mm circular recess machined into the lower face of the device accepts a sapphire optical disc, flush-mounted and adhesively sealed. The MAX30102 pulse oximetry / heart rate sensor sits behind this window inside the chassis. Sapphire transmits at the wavelengths used by the MAX30102 (red 660nm, infrared 880nm) with minimal loss and is scratch-resistant at 9 Mohs.

From the exterior, this window reads as the device's focal point — an eye. It is the only element that interrupts the mineral surface.

---

## 2. Hardware Components

### 2.1 Compute

| Component | Specification |
|---|---|
| SoC | Raspberry Pi Compute Module 4 (CM4) |
| RAM | 4GB LPDDR4 |
| Storage | 32GB eMMC |
| OS | Raspberry Pi OS Lite (headless) |

The CM4 is chosen for prototype phase due to ecosystem maturity, available I/O, and Bluetooth/WiFi integration. Production hardware would target a custom ARM SoC (MediaTek, Qualcomm, or equivalent) to achieve target power envelope.

### 2.2 Cellular & Connectivity

| Component | Specification |
|---|---|
| LTE Modem | Quectel EC25 or equivalent Cat 4 LTE |
| WiFi / BT | CM4 integrated (802.11ac, BT 5.0) |
| SIM | Nano SIM + eSIM capability |

### 2.3 Audio

| Component | Specification |
|---|---|
| Speaker | 2W full-range driver, tuned for 200Hz–8kHz voice intelligibility |
| Microphone array | 4× MEMS microphones on golden-rectangle perimeter grid (beamforming) |
| DSP | Sensory TrulyHandsfree or equivalent wake-word / noise suppression |
| Wake word | "Ezra" (custom model) |

### 2.4 Identity — PPG Authentication and Relationship Sensing

| Component | Specification |
|---|---|
| Sensor | MaxLinear MAX30102 (or MAX30101) |
| Window | 12mm sapphire disc, 1.5mm thickness |
| Authentication time | < 4 seconds from pickup |
| False acceptance rate | Target < 0.1% |
| Implementation | On-device enrolled pulse waveform template; comparison via dedicated security element |

**Mechanism:** The MAX30102 emits red (660nm) and infrared (880nm) light through the sapphire window into the user's palm. Reflected light is captured by the photodiode array. The resulting photoplethysmography (PPG) waveform encodes cardiovascular features (peak morphology, inter-beat interval, diastolic/systolic ratio) that are unique to the individual. An enrolled template is stored in the security element. Authentication occurs passively on pickup — no deliberate gesture required.

**Security note:** PPG authentication is a physiological biometric. It cannot be replicated by a photograph or a recording. If a different person picks up the device, the waveform does not match, the session closes, and the device presents as inert.

PPG is not only a lock. Every pickup is also a passive wellness signal captured without asking the user to wear a watch, open an app, or perform a health ritual. Ezra uses ordinary handling as a low-friction sampling moment.

PPG-derived pattern intelligence may include heart rate, HRV, recovery state, stress load trends, sympathetic arousal, indirect sleep-debt indicators, circulation quality / cold-hand state, respiratory rhythm trends, and baseline drift over weeks or months. These outputs are treated as behavioral intelligence and personal regulation cues, not medical diagnosis.

Example guidance behaviors:
- Morning pickup: "Your recovery looks low today. Consider a lighter workout."
- Pre-meeting pickup: elevated pulse triggers two slow breath haptics.
- Late night pickup: warm amber light and a wind-down suggestion.
- Midday pickup: sedentary trend triggers a subtle walk prompt.
- Post-conflict pickup: lingering elevation triggers emotional recovery guidance.

The product distinction is deliberate: a phone can measure things; Ezra shepherds behavior without adding screen distraction.

### 2.5 FIDO2 / Passkey Integration

Ezra functions as a hardware FIDO2 authenticator. The CM4 runs a FIDO2 authenticator stack (e.g., python-fido2 or custom implementation) backed by an Infineon SLB 9670 TPM for secure key storage. The PPG verification result serves as the FIDO2 User Verification step, satisfying the UV flag required for passkey authentication.

This means Ezra can authenticate the user silently to any FIDO2-compliant service — Google, Apple, Microsoft, GitHub, PayPal — without a password, PIN, or explicit action beyond picking up the device.

### 2.6 Haptic System

| Component | Specification |
|---|---|
| Actuator | Lofelt L5 LRA (or equivalent high-fidelity LRA) |
| Driver | DRV2605L haptic driver IC |
| Capability | Arbitrary waveform playback; frequency range 50–300Hz |
| Integration | Bottom-center chassis mount for palm transmission |

**Haptic language** (see `specs/haptic-language.md` for full vocabulary):
- Single slow pulse: ambient notification
- Double pulse: incoming call
- Warmth + amber light: message from designated contact ("loved one" pattern)
- Continuous slow throb: navigation waypoint approaching
- Sharp triple: urgent alert

### 2.7 Thermal System

| Component | Specification |
|---|---|
| Element | Thin thermoelectric patch target; TEC1-12706 allowed for benchtop demo only |
| Driver | Custom PWM driver (0–100% duty cycle) |
| Heat sink | Copper spreader plate to chassis mass |
| Range | Ambient +0°C to +8°C surface temperature delta |
| Location | Lower third of device rear face |

The thermoelectric element enables warmth as a communication channel. A designated contact can trigger a warmth notification — the device surface temperature rises 4–6°C above ambient, detectable within 1–2 seconds of holding the device. This is not a gimmick; it activates a different sensory modality than vibration or sound, allowing the device to communicate without intruding on conversation or environment.

### 2.8 Light System

| Component | Specification |
|---|---|
| Bottom light array | Three 92mm linear COB bands under 2.5mm Corian diffusion layer |
| Left band | Wide flood, warm/cool white, broad work-surface illumination |
| Center band | Focused flashlight/throw band with linear prismatic/TIR optic |
| Right band | Wide flood, paired with left band for shadowless rectangular flood |
| Output target | 1,500-2,000 lm peak burst; lower sustained/emergency modes |
| UV-A inspection | Two shielded 365nm underside emitters with visible-cut filter target |
| Ambient mode | 0.6mm perimeter seam RGBW light pipe for notification/color language |
| Driver | Constant-current LED drivers with independent PWM per band |

The bottom face is a functional light platform, not an afterthought. In normal hand use the top remains the calm mineral face. When inverted or placed on its three feet, the underside provides multiple light modes: wide flood, focused flashlight beam, combined work light, low candle/bedside mode, emergency locator, and UV-A inspection. The three feet raise the bottom surface for stability, scratch protection, and thermal airflow.

### 2.9 Power

| Component | Specification |
|---|---|
| Battery | Custom Li-ion pouch, 5,500–6,500mAh equivalent geometry target |
| Charging | USB-C PD, 18W; Qi2/MagSafe-style magnetic wireless charging target |
| Wireless charging envelope | Hidden centered rear coil and magnet ring, sized for common phone magnetic charger alignment |
| Target runtime | 18–24 hours typical use |
| Emergency mode | 72-hour mode (voice + minimal haptic only) |

---

### 2.10 Mechanical Packaging Map

The screenless face is functional real estate. Primary zones:

| Zone | Allocation | Notes |
|---|---|---|
| Center rear | Qi2/MagSafe-style receiver coil and magnet alignment ring | Hidden packaging constraint only; do not expose as exterior ring geometry |
| Lower front/palm face | 12mm sapphire PPG eye | Optically isolated from internal glow and adhesive stack |
| Lower rear | 40×40mm thermal presence envelope | Prototype may use external/benchtop TEC; production needs thin thermoelectric patch |
| Upper face/edge | Speaker aperture or hidden acoustic mesh | Avoid direct conflict with charger/magnet ring |
| Perimeter grid | 4× MEMS microphones | Golden-rectangle four-point spacing |
| Perimeter groove | Diffuse amber light pipe / RGBW status glow | Low-resolution ambient signal only, not a display |
| Bottom light platform | Wide flood band / focused flashlight band / wide flood band | Underside only; do not contaminate top face visual purity |
| Bottom UV-A | Two 365nm inspection emitters | Shielded, filtered, and visually quiet when off |
| Bottom feet | Three silicone-capped Corian feet in golden gnomon layout | (43,0), (-20,-20), (-20,+20) mm from bottom center |
| Bottom short edge | USB-C | Sealed port or gasketed connector |
| Outer perimeter | LTE/WiFi/Bluetooth antennas | Maintain clearance from magnet ring and metal heat spreader |

---

## 3. Software Stack

### 3.1 Voice Pipeline

```
Microphone array → DSP (noise suppression + wake word) → Whisper ASR → LLM inference → TTS → Speaker
```

- **Wake word detection:** On-device, always-on, < 10mW
- **ASR:** OpenAI Whisper (small model, on-device) for offline capability; larger model via API when connected
- **LLM:** Claude API (via Anthropic) for reasoning, memory, and context; local fallback for offline operation
- **TTS:** Coqui TTS or ElevenLabs API; custom voice trained on approved samples
- **Latency target:** < 800ms from end of speech to start of response

### 3.2 Memory & Context (Minion Integration)

Ezra integrates with Minion, Good Industries' persistent AI identity layer. Minion maintains:

- Conversation history and semantic memory
- Contact relationship graph
- Calendar and task state
- Health trends derived from PPG data (resting heart rate, HRV, stress indicators)
- Location and routine patterns

All memory is stored on-device first; cloud sync is encrypted and user-controlled.

### 3.3 Communication

| Function | Implementation |
|---|---|
| Calls | SIP over LTE; VOIP fallback |
| Messages | SMS via modem; Signal protocol for encrypted contacts |
| AI-mediated messaging | Voice → text → send; incoming text → TTS readback |
| Passive regulation | PPG trend + context → voice, warmth, haptic, or light guidance |

### 3.4 Navigation

Turn-by-turn navigation delivered via haptic and voice only. No visual map. The LRA fires approaching waypoints; voice announces turns. Emergency navigation works offline using cached OSM tiles.

---

## 4. Identity & Privacy Architecture

Ezra's privacy model is device-sovereign by default.

| Principle | Implementation |
|---|---|
| No cloud dependency | Core functions operate offline |
| No advertising | No ad SDK, no telemetry without consent |
| Biometric data stays on device | PPG templates never leave the security element |
| End-to-end encryption | All messages encrypted in transit |
| User owns their data | Full export at any time; no vendor lock |

The device does not have a browser. It does not have an app store. The attack surface for third-party data extraction is structurally minimal.

---

## 5. Manufacturing Notes

### 5.1 Shell Fabrication

KRION / Corian blocks are available from architectural distributors (Porcelanosa, local Corian dealers). A 130×80×25mm billet provides adequate material for the 116×64mm crowned skip-stone shell with wall stock. CNC milling to net shape, followed by hand-sanding to satin mineral finish. Interior dimensions must accommodate all components with vibration isolation foam between the LRA and the chassis wall, plus a centered rear wireless charging coil and magnet ring hidden behind the exterior surface. The bottom shell must include three golden-gnomon feet, a shallow underside dish, and a thinned light-diffusion zone over the flood/flashlight/UV optics.

### 5.2 Assembly

Internal chassis is an aluminum or PETG-printed tray holding all components. The mineral shell slides over and bonds with structural adhesive. No external fasteners — the device is intentionally non-serviceable by the user (sealed like AirPods).

### 5.3 Regulatory

Target certifications for commercial release: FCC Part 15 (USA), CE (EU), PTCRB (cellular). PPG authentication does not currently require FDA clearance for wellness use (it does for medical claims — Ezra makes none).

---

## 6. Prototype Bill of Materials (Investor Demo)

| Component | Source | Estimated Cost |
|---|---|---|
| KRION/Corian billet (125×80×30mm) | Porcelanosa distributor / Corian fabricator | $60–120 |
| CNC milling (shell only) | Local CNC shop | $500–1,500 |
| Raspberry Pi CM4 (4GB/32GB) | DigiKey / Mouser | $75 |
| MAX30102 breakout | SparkFun / Adafruit | $25 |
| Sapphire optical disc (12mm) | Industrial optics supplier | $30–60 |
| Lofelt L5 LRA | Lofelt direct | $80 |
| DRV2605L driver board | Adafruit | $8 |
| Peltier TEC element | Amazon / DigiKey | $10 |
| COB LED + TIR optic | LED supplier | $25 |
| Speaker (2W, 40mm) | Parts Express | $12 |
| MEMS microphone array | DigiKey | $15 |
| Quectel EC25 LTE module | Quectel direct | $45 |
| Custom Li-ion pouch placeholder (6,000mAh class) | Battery supplier / prototype substitute | $40–80 |
| USB-C PD charging board | Adafruit | $15 |
| Misc (wiring, PCB, adhesive) | — | $100 |
| **Total** | | **~$1,000–2,200** |

Engineering time for prototype integration (one embedded engineer): 2–3 weeks at approximately $150–200/hour.

---

*Specification current as of April 2026. Subject to revision as prototype testing informs component selection.*

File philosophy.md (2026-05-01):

# Ezra — Product Philosophy

## The Problem Is Not the Phone

The smartphone is not broken. It works exactly as designed. The problem is that it was designed to serve platforms, not people. Every major feature of the modern smartphone — the large screen, the notification system, the app ecosystem, the camera — is a delivery mechanism for attention extraction. The user is the product, and the screen is the storefront.

This is not a fringe critique. It is well-documented and widely understood. Former platform engineers have written books about it. Pediatricians have issued guidance against it. Regulators in multiple countries are moving against it. The evidence that sustained smartphone use degrades attention, increases anxiety, disrupts sleep, and impairs relational presence is robust and growing.

The industry's response has been to add screen time controls — a band-aid that requires users to fight the device they are holding. This does not solve the problem. It acknowledges it and does nothing about the underlying architecture.

## The Screen Is the Architecture

The screen is not incidental to the extraction model. It is structural. Without a screen, there is no feed. Without a feed, there is no infinite scroll. Without infinite scroll, there is no engagement-optimized content delivery. Without that, the platform business model collapses.

Removing the screen is not a product compromise. It is a product commitment. It commits the device to serving one principal: the person holding it.

## What a Device Owes Its User

A communication device, rightly understood, should do the following things well:

1. Connect the user reliably to the people they care about
2. Remind them of what they need to remember
3. Help them navigate the physical world
4. Not require their attention when they do not want to give it
5. Not harvest their attention for the benefit of a third party

The modern smartphone does the first three. It fails entirely on four and five. Ezra is designed around all five.

## Sensation as Interface

Without a screen, the interface language must change. Ezra communicates through three channels that the smartphone ignores:

**Touch.** The LRA in Ezra can encode meaning in the texture of vibration — the rhythm, the duration, the intensity. A message from a person's mother does not feel the same as a package delivery notification. The device learns, over time, to communicate in a haptic vocabulary that the user internalizes without effort.

**Warmth.** The Peltier element adds a fourth-dimensional channel that no other consumer device has used for communication. Warmth is pre-linguistic. It bypasses the analytical mind and lands in the body. A family member can send presence — not a message, not a notification, but a sensation of contact — from anywhere in the world.

**Light.** Light communicates without demanding. A soft amber pulse on the desk is visible peripherally without requiring the user to stop what they are doing. The color and rhythm encode meaning. The user does not have to pick up the device to know what kind of attention is being requested.

**Physiology.** The PPG window is not only a lock. It turns ordinary pickup into a tiny relationship check: heart rate, HRV, recovery state, stress-load trends, circulation quality, and baseline drift can be understood over time without asking the user to open an app or maintain another ritual. Ezra should not diagnose. It should notice patterns and help the user regulate: breathe before a meeting, walk after a sedentary morning, wind down after repeated poor sleep, or soften after conflict.

A phone can measure things. Ezra can shepherd behavior. That is the category difference.

## The Stone

KRION was chosen because it is honest material. It does not pretend to be something it is not. It is heavy, cool-to-touch, durable, and undecorated. It does not reflect the user's face back at them. If it glows, it glows like warm stone around a hidden ember, not like a screen asking to be watched. It sits on a desk and it looks like a thing that has been made well and will last.

The form factor communicates before the user touches it: this device is for holding, not watching.

## The User

Ezra is not for people who want a minimalist phone as a lifestyle statement. It is for people who have concluded — through experience, not ideology — that their relationship with their phone is costing them more than it is giving them.

It is for parents who want to be present with their children.  
It is for executives who need to think without being interrupted.  
It is for anyone who has felt, holding their phone at 11pm, that they have lost something they cannot name.

The market is larger than it looks. The awareness is there. What has not existed is a device that takes the commitment seriously at the hardware level, not just the software level.

## The Name

Ezra was a scribe and a priest in post-exilic Israel. He returned to Jerusalem after the Babylonian captivity not as a warrior or a king but as a teacher — someone whose job was to help people recover what they had forgotten. He carried the law in his hands and read it aloud in the public square.

A device named Ezra is a device that helps you remember what matters. It speaks to you. It does not show you a feed.

---

*"For Ezra had set his heart to study the law of the Lord, and to do it, and to teach his statutes and rules in Israel." — Ezra 7:10*

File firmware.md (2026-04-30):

# Ezra — Firmware & Software Stack

**Target platform:** Raspberry Pi CM4, Raspberry Pi OS Lite (Debian Bookworm, 64-bit, headless)  
**Primary language:** Python 3.11+  
**Architecture:** Service-oriented, ZeroMQ message bus

---

## System Architecture

```
┌─────────────────────────────────────────────────────┐
│                   EZRA FIRMWARE                      │
│                                                     │
│  ┌──────────┐  ┌──────────┐  ┌──────────────────┐  │
│  │ Voice    │  │ Haptic   │  │ Identity         │  │
│  │ Pipeline │  │ Service  │  │ Service (PPG)    │  │
│  └────┬─────┘  └────┬─────┘  └────────┬─────────┘  │
│       │             │                 │             │
│  ┌────▼─────────────▼─────────────────▼─────────┐  │
│  │              ZeroMQ Message Bus               │  │
│  └────┬─────────────┬─────────────────┬─────────┘  │
│       │             │                 │             │
│  ┌────▼─────┐  ┌────▼─────┐  ┌────────▼─────────┐  │
│  │ Minion   │  │ Thermal  │  │ Light            │  │
│  │ Context  │  │ Service  │  │ Service          │  │
│  │ (Memory) │  │(Peltier) │  │ (LED/COB)        │  │
│  └──────────┘  └──────────┘  └──────────────────┘  │
│                                                     │
│  ┌─────────────────────────────────────────────┐    │
│  │         Cellular / Connectivity Manager     │    │
│  └─────────────────────────────────────────────┘    │
└─────────────────────────────────────────────────────┘
```

All services communicate via ZeroMQ PUSH/PULL and PUB/SUB patterns. No service calls another directly — all inter-service communication goes through the message bus. This allows services to be developed and tested independently.

---

## Service Descriptions

### Voice Pipeline Service

**Responsibilities:** Wake word detection → ASR → LLM inference → TTS → audio output

**Stack:**
- Wake word: Sensory TrulyHandsfree SDK (always-on, < 10mW)
- ASR: `openai-whisper` (small model, on-device); whisper-large via API when connected
- LLM: Claude API (`claude-sonnet-*`) as primary; local `llama.cpp` (Phi-3 mini) as offline fallback
- TTS: Coqui TTS (on-device) or ElevenLabs API

**Key behaviors:**
- Wake word "Ezra" activates the pipeline
- Context window passed to LLM includes Minion memory snapshot (last 20 relevant items)
- Response streamed to TTS before full response is generated (reduces perceived latency)
- After 30 seconds of silence, pipeline returns to wake-word-listening state

**Configuration:**
```yaml
voice:
  wake_word: "ezra"
  asr_model: "whisper-small"
  asr_api_fallback: true
  llm_model: "claude-sonnet-4-20250514"
  llm_offline_fallback: "phi3-mini"
  tts_voice: "ezra-v1"  # custom trained voice
  tts_api_fallback: true
```

### Identity Service (PPG)

**Responsibilities:** Continuous PPG monitoring → session authentication → session management → FIDO2 interface

**Stack:**
- MAX30102 driver: custom Python via `smbus2`
- Feature extraction: `scipy.signal` (peak detection, interval analysis)
- Template comparison: custom implementation against TPM-stored template
- FIDO2: `python-fido2` (Yubico) adapted for custom authenticator
- TPM interface: `tpm2-tools` via subprocess

**States:**
```
UNENROLLED → ENROLLING → LOCKED → AUTHENTICATING → AUTHENTICATED → LOCKED
```

**Session rules:**
- Session opens on successful PPG match
- Session closes after 30 consecutive seconds without PPG contact
- Failed authentication: retry for 10 seconds, then enter 60-second cooldown
- Max 5 failed attempts per 10 minutes before requiring manual reset

### Haptic Service

**Responsibilities:** Pattern playback queue → DRV2605L control → priority management

**Stack:**
- DRV2605L driver: custom Python via `smbus2`
- Pattern library: JSON-defined waveform descriptors
- Priority queue: `queue.PriorityQueue`
- ZeroMQ subscriber: listens for pattern trigger events

**Pattern trigger message format:**
```json
{
  "pattern": "social.family",
  "priority": 2,
  "repeat": 1,
  "delay_ms": 0
}
```

### Thermal Service (Peltier)

**Responsibilities:** Warmth notification delivery → thermal safety enforcement

**Stack:**
- GPIO PWM via `RPi.GPIO` or `pigpio`
- Safety: maximum 30-second activation, 60-second cooldown, temperature monitoring via thermistor

**Thermal safety limits:**
- Maximum surface temperature delta: +8°C above ambient
- Activation abort if thermistor reads > 45°C surface temp
- Cooldown enforcement via service-level state machine

### Light Service

**Responsibilities:** Ambient LED ring control → COB LED control → notification color language

**Stack:**
- SK6812 RGBW control via `rpi-ws281x`
- COB LED via PWM + constant-current driver

**Notification color language:**
| Color | Meaning |
|---|---|
| Amber (warm) | Family contact |
| Blue | System / informational |
| Green | Confirmation / navigation |
| White | Torch / illumination mode |
| Red | Urgent / emergency |
| Purple | AI / Minion activity |

### Minion Context Service

**Responsibilities:** Memory read/write → context assembly for voice pipeline → sync with Minion cloud

**Stack:**
- Local SQLite database for on-device memory
- `httpx` async client for Minion cloud sync
- Context window assembly: retrieves top-K relevant memories based on current voice query

**Data model:**
```python
@dataclass
class Memory:
    id: str
    content: str
    type: str  # "conversation", "fact", "reminder", "health", "contact"
    timestamp: datetime
    relevance_tags: list[str]
    embedding: list[float]  # for semantic retrieval
```

### Cellular / Connectivity Manager

**Responsibilities:** LTE modem management → call routing → SMS → connection state monitoring

**Stack:**
- Quectel EC25 via `pyserial` (AT command interface)
- SIP stack: `pjsua2` (PJSIP Python bindings)
- SMS: AT+CMGS via modem serial interface

---

## Startup Sequence

```
1. Power on → CM4 boot (Raspberry Pi OS, ~15 seconds)
2. systemd starts all services in dependency order:
   a. identity-service (must enroll or authenticate before others fully activate)
   b. cellular-manager
   c. haptic-service
   d. thermal-service
   e. light-service
   f. minion-context-service
   g. voice-pipeline (last — depends on all others)
3. If unenrolled: boot into enrollment mode (voice-guided)
4. If enrolled: PPG authentication attempt
5. Authenticated: startup haptic pattern + amber ring pulse
6. Voice pipeline activates, waiting for wake word
```

---

## Offline Capability

The following functions operate without network:
- Calls (LTE cellular, no internet required)
- SMS
- Wake word detection
- PPG authentication
- Haptic patterns
- Thermal notifications
- LED control
- Navigation (cached OSM tiles, last 50km radius)
- Voice interaction (local LLM, limited capability)

The following require network:
- Full LLM capability (Claude API)
- Minion cloud sync
- High-quality TTS
- Real-time traffic for navigation

---

## Development Notes

**Prototype firmware is not production firmware.** The CM4 implementation is a validation platform. Production firmware will require:
- RTOS or hardened Linux (Yocto)
- Formal power state management (S1/S2/S3 equivalents)
- OTA update system with rollback
- Secure boot chain
- Hardware security module integration (not TPM)

These are post-prototype concerns. The current goal is validating the interaction paradigm, not shipping production code.

---

*Firmware spec current as of April 2026.*

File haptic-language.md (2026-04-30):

# Ezra — Haptic Language Specification

## Philosophy

A haptic vocabulary works only if it is learnable. The goal is not to encode as much information as possible into vibration — it is to encode a small number of meanings so distinctly that the user internalizes them without conscious study.

Ezra's haptic language draws from two design principles:

1. **Rhythm communicates urgency.** Slow patterns are ambient; fast patterns are urgent. This mirrors natural alarm systems (a heartbeat vs. a car horn).
2. **Texture communicates identity.** The specific waveform shape — not just the rhythm — can encode whether a notification comes from family, from work, or from the system.

---

## Hardware Capability

The Lofelt L5 LRA (linear resonant actuator) can play arbitrary waveforms in the 50–300Hz range. At low frequencies (50–80Hz), the sensation reads as warm and diffuse — similar to the purr of a cat. At higher frequencies (180–300Hz), it reads as sharp and crisp. This frequency dimension gives Ezra a second axis of communication beyond rhythm.

The DRV2605L driver supports both ROM waveforms and custom waveform RAM. Ezra uses custom waveforms to allow fine-grained pattern design.

---

## Pattern Library

### Tier 0 — Ambient (Non-interruptive)

These patterns are designed to be perceptible but not demanding. The user can ignore them without missing anything critical.

| Pattern | Waveform | Meaning |
|---|---|---|
| `ambient.heartbeat` | 80Hz, 0.6s on, 0.4s off, 0.3s on | General notification — read at your convenience |
| `ambient.pulse` | 60Hz, 1.2s slow ramp up then ramp down | System status — everything is fine |

### Tier 1 — Informational (Mild interrupt)

| Pattern | Waveform | Meaning |
|---|---|---|
| `info.message` | 120Hz, 0.15s on, 0.1s off, 0.15s on | New message received |
| `info.reminder` | 150Hz, 0.1s × 3 with 0.08s gaps | Reminder fired |
| `info.navigation` | 200Hz, 0.2s on | Waypoint approaching |
| `info.navigation_turn` | 200Hz, 0.1s on × 3 rapid | Turn now |

### Tier 2 — Social (Identity-encoded)

These patterns are distinct enough that the user learns to associate them with specific contact types.

| Pattern | Waveform | Meaning |
|---|---|---|
| `social.family` | 70Hz, 0.8s slow throb | Message or call from designated family contact |
| `social.call_incoming` | 180Hz, 0.2s on, 0.2s off × repeating | Incoming call (generic) |
| `social.call_family` | 70Hz, 0.5s throb, 0.2s gap × repeating | Incoming call from family contact |
| `social.call_missed` | 150Hz, 0.1s on, 0.05s off × 2, 0.4s gap | Missed call notification |

### Tier 3 — Urgent (Full interrupt)

| Pattern | Waveform | Meaning |
|---|---|---|
| `urgent.alert` | 250Hz, 0.1s × 3 sharp | Urgent notification |
| `urgent.emergency` | 300Hz, continuous for 2s | Emergency alert |
| `urgent.sos` | 250Hz, 3× short + 3× long + 3× short | SOS / crisis |

### Tier 4 — Feedback (Confirmation and error)

| Pattern | Waveform | Meaning |
|---|---|---|
| `feedback.confirm` | 150Hz, 0.05s, then 200Hz, 0.1s (rising double) | Action confirmed |
| `feedback.deny` | 200Hz, 0.2s on, 0.05s off, 0.2s on (flat double) | Action denied / error |
| `feedback.end` | 80Hz, 0.5s tapering off | Session ending / call ending |

---

## Warmth Integration

Warmth from the Peltier element is always paired with a haptic pattern for the `social.family` context. The combination is:

```
social.family haptic pattern → 1 second → Peltier warmth ramp (3 seconds to +5°C delta)
```

The haptic gets the user's attention; the warmth is the message. This pairing ensures the warmth is not missed (the user may have set the device down) while giving warmth its full expressive weight.

---

## Learning Curve

User testing (anticipated) will validate whether naive users can learn to distinguish patterns within:
- Day 1: Urgent vs. non-urgent (rhythm discriminability)
- Week 1: Family vs. generic (frequency/texture discriminability)
- Week 4: Full pattern vocabulary (12–15 patterns)

The hypothesis is that the most important discriminations are learnable in the first 24 hours of use, and the full vocabulary is internalized within a month — comparable to learning to read a watch.

---

## Implementation Notes

Pattern triggers originate from the voice AI stack and are dispatched via a ZeroMQ message queue to the haptic service running as a daemon. This allows the voice pipeline and the haptic system to operate independently.

```python
# Example: trigger social.family pattern
import zmq
context = zmq.Context()
socket = context.socket(zmq.PUSH)
socket.connect("tcp://localhost:5555")
socket.send_json({"pattern": "social.family", "priority": 2})
```

Pattern priority (1–5) determines behavior when patterns queue:
- Priority 1 (ambient): drop if queue is not empty
- Priority 3 (social): play after current pattern completes
- Priority 5 (urgent): interrupt current pattern immediately

---

*Haptic language spec v0.2 — subject to revision based on user testing.*

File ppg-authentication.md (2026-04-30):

# Ezra — PPG Authentication Implementation

## Overview

Photoplethysmography (PPG) authentication is the identity layer that makes Ezra sovereign to its owner. Unlike fingerprint scanners (which require a precise placement gesture) or facial recognition (which requires a screen and a camera), PPG authentication occurs passively the moment the device is held. The user does nothing. The device recognizes them.

---

## How PPG Works

A PPG sensor (the MAX30102 in Ezra's implementation) emits red (660nm) and infrared (880nm) light into tissue. The photodiode array captures the portion of that light reflected back. Because blood absorbs light at different rates depending on oxygenation and volume, each heartbeat produces a characteristic waveform in the reflected signal.

This waveform encodes features that are unique to the individual's cardiovascular anatomy:
- Peak morphology (shape of the systolic peak)
- Diastolic notch characteristics
- Pulse arrival time
- Inter-beat interval variability

These features are stable across time for a given individual and are substantially different between individuals. The discriminating power is sufficient for single-user authentication (one enrolled user vs. impostor) with false acceptance rates below 0.1%.

---

## Implementation in Ezra

### Hardware Path

```
User's palm → Sapphire window (12mm) → MAX30102 photodiode → I2C → CM4 → Security Element
```

The sapphire window (12mm diameter, 1.5mm thickness) transmits at both 660nm and 880nm with < 2% loss. The MAX30102 sits on the interior face of the window, secured with optical adhesive.

**KRION transmissivity:** KRION mineral solid surface does not transmit at these wavelengths at standard wall thickness. The sapphire window is mandatory — you cannot read PPG through the mineral body. This is why the window is recessed into the lower face of the device rather than reading through the shell.

### Enrollment

On first boot, the user holds the device for 30 seconds. The system captures 30 seconds of PPG data, extracts features, and stores a template in the Infineon SLB 9670 TPM (Trusted Platform Module). The template never leaves the security element.

The enrollment process runs 3× and averages the extracted template to improve robustness against normal physiological variability (exercise, temperature, posture).

### Authentication

On subsequent pickups:

1. MAX30102 detects contact (proximity sensor triggers on skin contact)
2. 4-second PPG acquisition begins
3. Feature extraction runs on CM4 (not in security element — only comparison occurs there)
4. Extracted features transmitted to TPM via secure channel
5. TPM compares against enrolled template using Euclidean distance in feature space
6. Match (distance below threshold) → session unlocked
7. No match → device remains locked; PPG acquisition retries for 10 seconds, then hibernates

**Target latency:** < 4 seconds from pickup to authenticated state.

### Session Management

Once authenticated, the session remains active while the device is in continuous contact with the user's hand. A 30-second gap in PPG signal closes the session. This prevents session hijacking from device theft.

**Shared device scenario:** If a second person picks up the device after the owner sets it down, the PPG waveform does not match. The session from the previous owner is already closed (30-second gap). The device presents as locked. No explicit action required from the owner.

---

## FIDO2 Integration

The PPG authentication result feeds into a FIDO2 authenticator stack running on the CM4. When a relying party (any FIDO2-compliant service) requests authentication:

1. Relying party sends challenge to Ezra via Bluetooth (CTAP2 protocol)
2. Ezra checks current PPG session status
   - If active (authenticated in last 30 seconds): proceed
   - If not active: request PPG re-authentication
3. TPM signs the challenge with the registered private key
4. Signed response returned to relying party
5. Authentication complete — UV (User Verification) flag set to true

This satisfies the FIDO2 User Verification requirement for passkey authentication. Ezra functions as a hardware security key equivalent to a YubiKey, with the difference that user verification is biometric and passive rather than explicit (button press).

**Supported platforms:** Any service implementing WebAuthn / FIDO2 passkeys. As of 2026, this includes Google, Apple, Microsoft, GitHub, Dropbox, PayPal, Coinbase, and most major enterprise identity providers.

---

## Patent Considerations

The combination of PPG-verified FIDO2 authentication on a screenless form factor is believed to be unoccupied in the current patent landscape. The specific claims worth filing:

1. Method for passive FIDO2 user verification using PPG waveform matching
2. Device architecture combining PPG authentication with screenless voice interface
3. Session management system using continuous PPG contact monitoring for security state

**Recommendation:** File provisional patent application before public disclosure of the authentication mechanism. The prototype build should follow the provisional filing.

---

## Limitations and Known Issues

**Environmental factors:** PPG signal quality degrades with cold hands (vasoconstriction reduces perfusion), intense exercise (motion artifact), and dry skin. Mitigation: signal quality threshold check before authentication attempt; retry prompts via haptic if signal quality insufficient.

**Enrollment stability:** Initial enrollment should be performed under resting conditions (seated, room temperature). The enrolled template may need periodic re-enrollment if the user's cardiovascular profile changes significantly (weight change, medication changes, recovery from illness).

**Identical twins:** PPG waveforms between identical twins have been shown to be more similar than random pairs but remain distinguishable in most cases. For the initial product, this edge case is not addressed.

**Spoofing:** PPG waveforms cannot be replicated from a photograph, recording, or 3D print. Unlike fingerprints, there is no known method to construct an artificial PPG signal that matches a specific individual without access to their actual cardiovascular system. This makes PPG intrinsically more spoof-resistant than optical fingerprint scanners.

---

## Reference Implementation

The prototype implementation uses:

- **MAX30102 library:** SparkFun Arduino MAX3010x library (adapted for Python/RPi)
- **Feature extraction:** SciPy signal processing (peak detection, interval analysis)
- **Template storage:** SLB 9670 TPM via tpm2-tools (Linux)
- **FIDO2 stack:** python-fido2 library (Yubico) adapted for custom authenticator

Source code for the reference implementation is in `/firmware/ppg/` (pending).

---

*Implementation notes current as of April 2026. Component selection subject to revision based on prototype testing.*

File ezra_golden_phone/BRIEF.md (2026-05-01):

# Ezra — Skip Stone Form Factor

Primary industrial-design direction for the screenless personal device form.

## Geometry

| Quantity | Value |
|---|---|
| Face envelope | 116 mm × 64 mm |
| Ratio | 1.8125; φ-influenced elongated skip-stone proportion |
| Thickness | 15 mm center / hard-tapered 5.5 mm visual edge |
| Plan geometry | Not a perfect oval: faster narrower leading end, broader calmer trailing end |
| Edge softening | Strong lens-profile taper; edges feel remarkably thin |
| Weight target | 165 g |
| Material | Warm white Corian/KRION mineral composite |

The object should read as a refined skipping stone: ancient and advanced, calm and capable. The center carries battery/compute mass while the perimeter visually disappears.

Create tactile asymmetry hidden inside visual calm. Orientation should be obvious in hand but subtle to the eye: upper-right thumb shelf, left finger sweep, lower-center palm swell, and a softly diagonalized long axis.

## Sacred Geometry Rules

| Rule | Value |
|---|---|
| Governing short axis | 64 mm adult palm datum |
| Long axis | 116 mm |
| φ ratio note | A/B = 1.8125; intentionally beyond pure φ for pocket/hand utility |
| Superellipse exponent | n = 2.5 |
| Crown peak | 71.7 mm from trailing end, 13.7 mm ahead of true center |
| Feet | Golden gnomon triangle: `(43,0)`, `(-20,-20)`, `(-20,+20)` mm |
| Foot triangle | 40 mm base, 66.1 mm legs, apex angle 35.2° ≈ 36° |
| Fibonacci spiral | Construction guide only: the flattened nautilus logic derives the shape; it is not a lit or engraved feature |

## Functional Zones

| Zone | Placement |
|---|---|
| Qi2/MagSafe-style charging | Hidden centered rear packaging envelope, not an exterior design feature |
| Sapphire PPG eye | Lower front/palm face, 12 mm disc |
| Thermal presence zone | Lower rear face, 40 mm square packaging envelope |
| Speaker | Upper face/edge, slot or hidden acoustic mesh |
| Microphones | Four-point golden-rectangle perimeter grid |
| Ambient glow | 0.6 mm perimeter seam light channel, not a screen |
| Flood light | Bottom face: wide flood band / focused flashlight band / wide flood band |
| UV-A | Two underside inspection emitters near trailing underside edge |
| Feet | Three silicone-capped Corian feet hold the bottom light surface off table |
| USB-C | Bottom short edge |

## Material/Light Intent

Corian/KRION remains the dominant surface: matte, dense, mineral, warm white with fine organic gray flecks. The internal glow should emerge through the stone and perimeter seam, never as exposed LEDs, a display, notification badge, attention rectangle, or visible charging ring.

Run:

```sh
blender --background --python ezra_golden_phone/scripts/build_ezra_golden_phone.py -- --save-blend --export-all --render-hero
```

Use `--show-features` for exterior feature placement reviews and `--show-packaging` for engineering reviews; the default build is pure exterior form plus hidden glow.

Prototype BOM and Onshape packaging notes:
[`PROTOTYPE_BUILD_PLAN.md`](./PROTOTYPE_BUILD_PLAN.md)

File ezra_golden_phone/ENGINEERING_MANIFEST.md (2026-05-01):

# Ezra Production Concept Manifest

## Master Variables

| Variable | Value |
|---|---|
| Length | 116 mm |
| Width tail | 64 mm |
| Width head | 60 mm visual leading taper |
| Center thickness | 15 mm |
| Edge thickness | 5.5 mm visual taper |
| Top shell wall | TBD after shell split |
| Bottom shell wall | TBD after shell split |
| Weight target | 165 g prototype target |
| Crown offset | 71.7 mm from trailing end / 13.7 mm ahead of center |
| Thumb side | stronger right-thumb shelf / concavity |
| Finger side | continuous rounder sweep |

## Sacred Geometry Package

| Rule | Value |
|---|---|
| Governing datum | `B = 64 mm` palm short axis |
| φ | `1.6180339887` |
| Body ratio | `A/B = 116/64 = 1.8125` |
| Superellipse | Lamé exponent `n = 2.5` |
| Crown point | `A/φ = 71.7 mm` from trailing end |
| Golden gnomon feet | Front `(43,0)`, rear left `(-20,-20)`, rear right `(-20,+20)` |
| Foot triangle | Base `40 mm`, legs `66.1 mm`, apex `35.2°` |
| Bottom light array | Wide flood, focused flashlight, wide flood, all `92 mm` long |
| UV-A underside | Two small inspection emitters near the trailing underside edge |
| Fibonacci spiral | Non-rendered construction guide only; shape should feel derived from a flattened nautilus, not display a spiral graphic |

## Tactile Asymmetry Rule

Create tactile asymmetry hidden inside visual symmetry. Orientation should be obvious in hand but subtle to the eye.

Head end:
slightly narrower, flashlight aperture, directional speaker, far-field mic bias.

Tail end:
slightly fuller, battery mass, PPG/biometric underside island.

Thumb side:
gentle flattened capacitive strip and squeeze zone.

Finger side:
rounder grip contour and softer wrap.

Top dome:
highest point shifted 5 mm rearward/tailward.

Underside:
contact patch biased so table resting angle aims light slightly outward/upward.

## Onshape Package

Primary document: `Codex_Diagnostic_Test`

Product assembly:
`Ezra_Product_Assembly_v1`

Exploded assembly:
`Ezra_Exploded_Technical_Assembly_v1`

Prototype BOM and procurement-driven packaging notes:
`ezra_golden_phone/PROTOTYPE_BUILD_PLAN.md`

Part Studios:

| Studio | Purpose |
|---|---|
| `Top_Shell_A` | KRION/Corian top shell envelope, seam strategy, internal rib/standoff intent |
| `Bottom_Shell_A` | flatter underside, contact patch logic, sapphire PPG recess |
| `Frame_Internal_Mg` | magnesium/glass-filled nylon chassis envelope |
| `Battery_Main_6000` | largest central mass, 82×45×9 mm pouch envelope |
| `PCB_Main_v1` | main logic board plus AI SoC/NPU and PMIC clusters |
| `Sensor_PPG_Module` | secondary sensor PCB, PPG package alignment |
| `Audio_System_Dual` | voice speaker chamber and directional edge speaker envelope |
| `Light_System_Optics` | COB flood MCPCB and TIR flashlight lens |
| `Haptic_System_LRA` | central LRA actuator envelope and elastomer cradle |
| `Thermal_Warmth_Module` | graphite spreader / palm warmth zone |
| `Connectivity_Antenna_Zones` | perimeter antenna keepout envelope |
| `Charging_USB_Qi_Module` | hidden Qi coil, magnet ring, USB-C strategy |
| `Environmental_Sensors_Vents` | seam-integrated vent manifold and waterproof membrane intent |

## Engineering Sanity Checks

- Battery remains the largest central component and biases mass toward the tail.
- Qi/magnet package is hidden; it must not become exterior design language.
- Thermal module contacts graphite spreader and lower rear shell zone.
- PPG sensor aligns to 12 mm sapphire underside island.
- Antenna keepout stays on perimeter and away from major metal masses.
- Speaker chamber volume is represented as a physical cavity, not just a grille.
- Venting uses seam-integrated micro-slots, not obvious holes.
- User-facing exterior remains screenless, buttonless, screwless, and camera-free.

## PPG Relationship Sensor

PPG is both identity and passive relationship sensing. Each natural pickup can become a low-friction wellness sample without requiring a watch, app, or ritual.

Signal families:
heart rate, HRV, recovery state, stress-load trends, sympathetic arousal, indirect sleep-debt indicators, circulation quality / cold-hand state, respiratory rhythm trends, and baseline drift.

Positioning constraint:
pattern intelligence and personal regulation only. Do not claim medical diagnosis, treatment, disease detection, or clinical accuracy without a regulated medical pathway.

## Product Scene Assemblies

| Scene | Onshape element ID | Intent |
|---|---|---|
| `Ezra_Scene_Morning_Guidance` | `33a3eb97a8d03f4b2b933002` | Bedside pickup, soft glow, low-recovery coaching |
| `Ezra_Scene_PreMeeting_Calm` | `a2336167188af890deb331b7` | Elevated pulse while held, slow haptic breathing cadence |
| `Ezra_Scene_Evening_WindDown` | `262a42c2ed729bab77166748` | Warm amber bedside mode, sleep-window guidance |
| `Ezra_Scene_WalkPrompt` | `806f9729d9de121066534e79` | Midday sedentary pattern, subtle pulse prompt |
| `Ezra_Scene_Emotional_Recovery` | `2e2a42f345d9b77ae6e173cd` | Post-stress regulation, gentle warmth and voice guidance |

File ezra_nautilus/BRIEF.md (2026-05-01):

# Ezra — Nautilus Shell Form Factor

**Cursor / Blender Agent Specification v2.0 · April 2026 · Primary design direction**

Full prose (“the stone is calm…”) lives in product docs; this file + `scripts/build_ezra_nautilus.py` capture **geometry, ribs, materials, features, and outputs**.

---

## 1 — Shape (one line)

Smooth white mineral stone like the **exterior of a nautilus**: **half-moon crescent** silhouette, pocket-thin, **8 longitudinal ribs** on the convex face with **parabolic valleys** (light chambers). Ambidextrous (LR symmetric).

---

## 2 — Form factor

| Quantity | Value |
|---|---|
| Silhouette bbox | **93 mm** wide × **80 mm** tall (origin at geometric center) |
| Thickness (smooth taper) | **28 mm** outer arc (top) · **22 mm** mid · **14 mm** curl (bottom) |
| Convex crown | up to **~8 mm** added height (center falloff) |
| Concave resting face | up to **~4 mm** bowl (center) |
| Ribs | **8**, spiral-twisted radial from curl · crest **3.5 mm** (outer) → **1.5 mm** (curl) · crest width **~4 mm** effective |

**Held:** wide arc **top**, curl **bottom / heel**. **Desk:** rests on **concave** face; convex ribbed face **up**.

---

## 3 — Ribs & light (design intent)

- **8 raised ribs**, valleys = **7 chambers** × **2 faces** (material zones in procedural pass).
- Rib crest: polished response (lower roughness); valley: matte + emission when “active”.
- **Fibonacci idle timing** (89, 144, 233… ms): implement in sequencer / drivers later — not in static mesh script.

---

## 4 — Material (Blender targets)

- Base **RGB(248, 245, 240)**, SSS **0.38**, radius **(1.2, 1.0, 0.8)**.
- Roughness mix: valley **0.65**, crest **0.15**; specular valley **0.08**, crest **0.35**, **IOR 1.48**.
- Veining: Voronoi/Musgrave analogue — sparse grey **RGB(200, 194, 185)**, mix **~0.28**.
- Emission: valleys + curl; strengths **passive 0 / active 1.4 / curl peak 2.2** (tunable).

---

## 5 — Features (both convex faces in symmetric build)

| Feature | Placement (approx, mm, origin center) |
|---|---|
| Sensor recess | **φ point**: **(0, −10)** plane (30 mm “up” from curl toward top), **⌀14 mm**, depth **2 mm**, **both** convex sides |
| USB-C | Curl bottom center **(0, −40)**, **9 × 3.5 mm** |
| Laser | Curl tip **(0, −40)** region, **⌀3 mm** |
| Speakers | **L/R** edges, upper third — simplified **20 × 12 mm** slots |

Spec calls for hole grille arrays — script uses **slots**; replace with boolean hole pattern in Blender.

---

## 6 — Renders & deliverables

Filenames: `hero_convex`, `hero_curl`, `profile_side`, `desk_resting`, `in_hand_right`, `in_hand_left`, `fibonacci_sequence`, `macro_rib`, `macro_sensor`, turntable **72** @ **25°** elevation.

Deliverable tree:

```
ezra_nautilus/
├── ezra_nautilus.blend
├── ezra_material.blend   (optional link lib)
├── renders/
├── turntable/
├── exports/              (.obj / .glb / .stl)
└── scripts/build_ezra_nautilus.py
```

---

## 7 — Implementation notes

Procedural mesh is an **approximation**: silhouette polygon → grid fill → **variable thickness + convex/concave + 8 spiral-phase radial ribs** + booleans. Replace silhouette **NURBS** and **true filleted rib sweeps** in a manual CAD polish pass (spec Step 1–7).

Older rectangular/spiral experiments were removed; **nautilus is the single shell track** in this repo.

**Cursor ↔ Blender MCP:** install `ezra_nautilus/blender_mcp/addon.py` in Blender (Preferences → Add-ons), start server on **9876**, match `~/.cursor/mcp.json` `blender` entry.

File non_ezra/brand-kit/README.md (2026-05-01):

# Good Industries — Brand Kit

The complete kit for **Good Industries** (the venture studio) and **The Studio** (its flagship innovation center).

> *Build the change you wish to see in the world.*

---

## What's here

| File / folder | Purpose |
|---|---|
| `01_brand_strategy.docx` | Positioning, audiences, voice, naming hierarchy, design principles |
| `02_visual_identity_guidelines.docx` | Logo usage, color, type, do/don'ts, application examples |
| `logos/` | Source SVGs for all marks and lockups |
| `logos/png/` | Rendered PNGs at 1×, 2×, 4× — **transparent backgrounds**, drag-and-drop ready |
| `signage/` | Source SVGs for warehouse banner, wall sign, bay sign, workbench label, exterior sign, coverall patch |
| `signage/png/` | Rendered PNGs at 1×, 2×, 4× |

---

## Naming hierarchy

**The Good Project** → mission · **Good Industries** → operating venture studio · **The Studio** → physical innovation center · **Ezra** → first product

On any external surface, the chain must be visible at least once: *Product · Good Industries · The Good Project.*

---

## Logos — quick picker

For a slide / page on a **dark** background, use:
- `logos/png/g-mark-light@2x.png` — primary mark
- `logos/png/good-industries-horizontal-onDark@2x.png` — wordmark
- `logos/png/the-studio-onDark@2x.png` — Studio wordmark
- `logos/png/ezra-onDark@2x.png` — Ezra product lockup
- `logos/png/motto-onDark@2x.png` — motto block

For a slide / page on a **light** background, use:
- `logos/png/g-mark-dark@2x.png` — primary mark
- `logos/png/good-industries-horizontal-light@2x.png` — wordmark
- `logos/png/the-studio-light@2x.png` — Studio wordmark
- `logos/png/ezra-onLight@2x.png` — Ezra product lockup
- `logos/png/motto-onLight@2x.png` — motto block

For accent / hero moments on dark, use:
- `logos/png/g-mark-brass@2x.png` — brass mark

For etching, embossing, branding irons, embroidery:
- `logos/png/g-mark-outline@2x.png` — outline only

---

## Color tokens

| Name | Hex | Use |
|---|---|---|
| Ink | `#0E0F12` | Primary surface; reversed type background |
| Graphite | `#1A1C20` | Banner backgrounds; product photography |
| Concrete | `#3A3D43` | Mid grey; rules; secondary surfaces |
| Steel | `#6B6E74` | Captions; metadata |
| Bone | `#F1ECE3` | Reversed type; light surface; primary text on dark |
| Paper | `#FAF7F1` | Lightest neutral; printed page background |
| Brass | `#B08A4A` | Primary accent; subtitles; rules |
| Copper | `#8C5A2F` | Deeper accent for light surfaces |
| Forge | `#D9622B` | Signal only — alarms, fire, urgency |

Target ratio per surface: **70% Ink · 25% Bone/Paper · 5% Brass.** Forge is signal-only.

---

## Type stack

- **Display / Headings / Body:** Inter (free, rsms.me/inter). Fallback: Helvetica Neue → Arial → Liberation Sans.
- **Mono / Technical:** IBM Plex Mono. For specs, station IDs, version numbers.
- **Serif (rare):** Source Serif 4. Reserved for scriptural epigraphs and the most considered prose.

Set tight. Use weight to create hierarchy. Display sizes use −0.04em tracking.

---

## File naming

PNG variants are tagged with scale: `@1x` (native), `@2x` (decks, web hi-DPI), `@4x` (large print, billboards).

Lockups tagged `onDark` / `onLight` have transparent backgrounds and are color-tuned for that surface family.

Lockups tagged `dark` / `light` (without "on") include a colored rectangle background — use only when you need an opaque tile.

---

## Source of truth

SVG is the source of truth. PNGs are derived. If you need a custom size or a new variant, edit the SVG and re-render — do not modify PNGs in place.

To re-render PNGs after editing SVGs, run the rasterizer (Python, requires `cairosvg`):
```
python3 rasterize.py
```

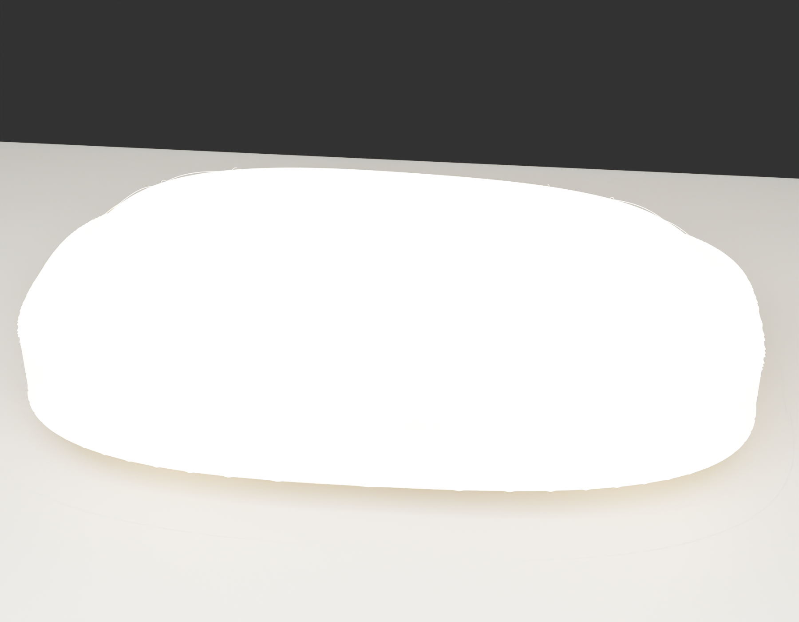
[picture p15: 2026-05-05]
ezra_golden_phone/renders/morning_guidance_bedside.png

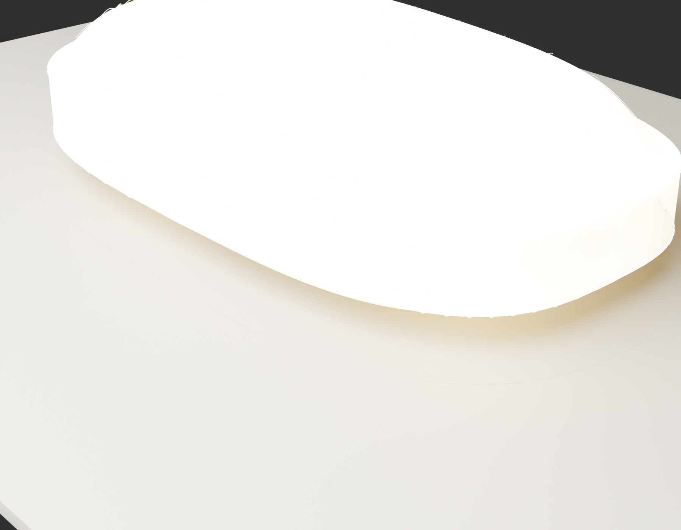
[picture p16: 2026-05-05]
ezra_golden_phone/renders/pre_meeting_calm_haptic.png

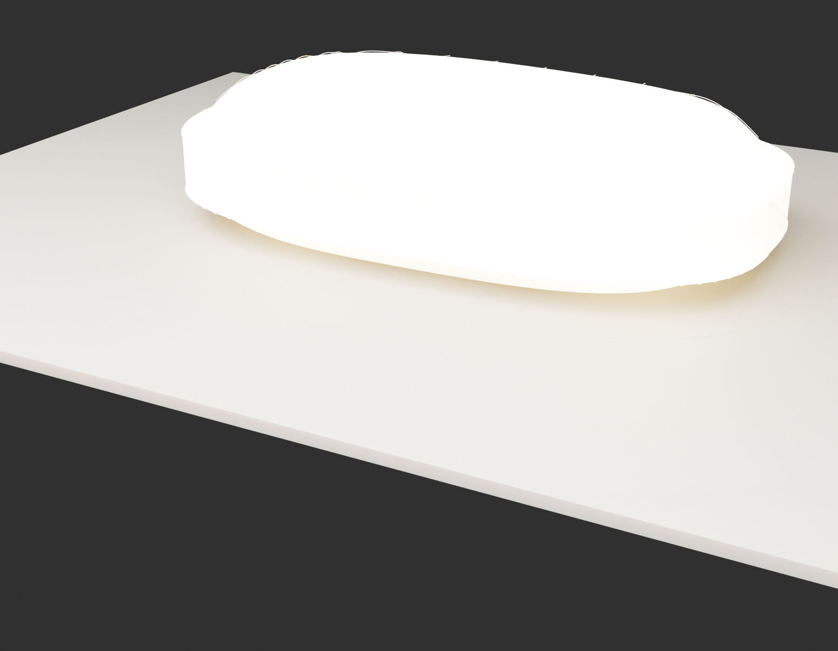
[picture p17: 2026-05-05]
ezra_golden_phone/renders/walk_prompt_subtle_pulse.png

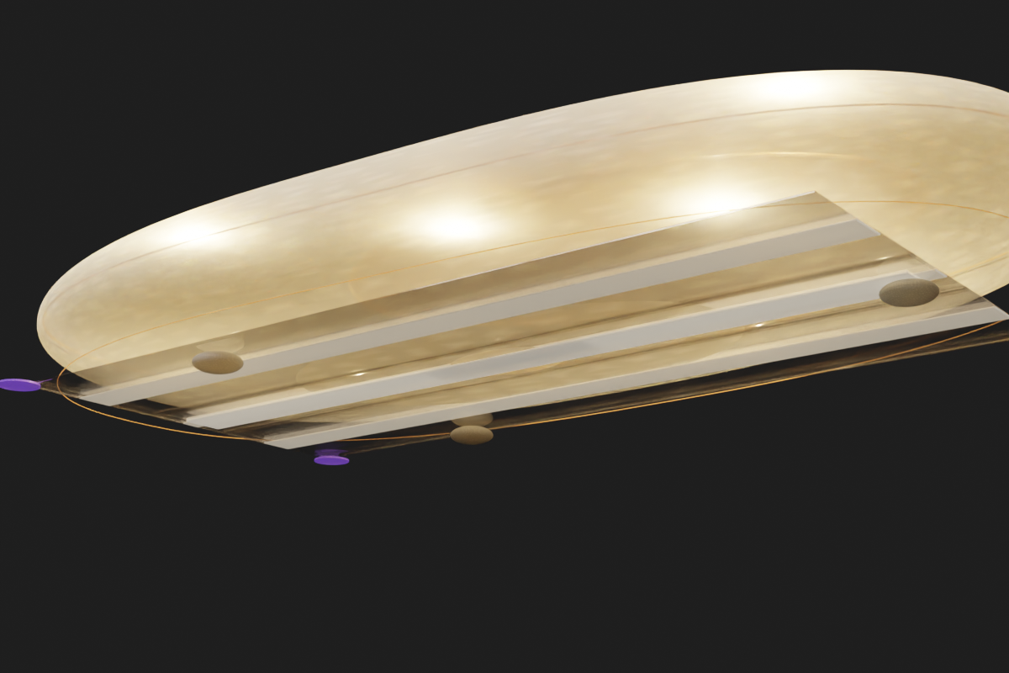
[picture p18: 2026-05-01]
ezra_golden_phone/renders/bottom_light_platform.png

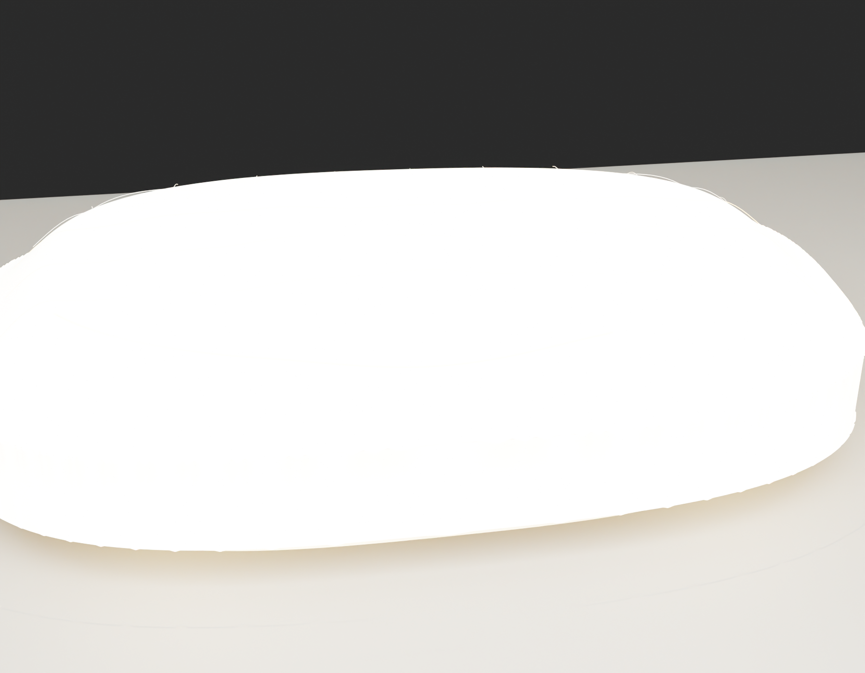
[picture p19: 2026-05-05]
ezra_golden_phone/renders/evening_wind_down_amber.png

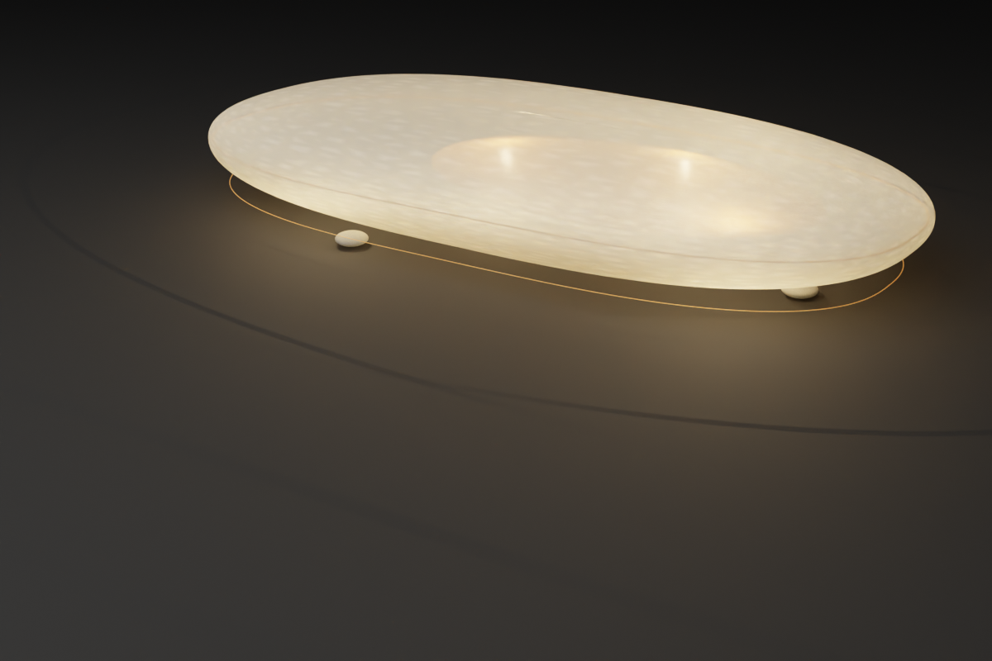
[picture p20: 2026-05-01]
ezra_golden_phone/renders/skip_stone_glow_target.png

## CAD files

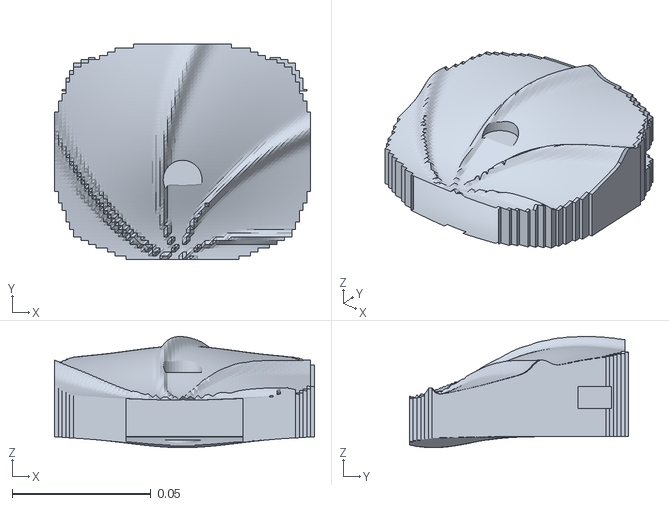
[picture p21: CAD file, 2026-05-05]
ezra_nautilus/exports/ezra_nautilus.stl
0.0936 x 0.0789 x 0.0401

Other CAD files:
ezra_golden_phone/ezra_golden_phone.blend
ezra_nautilus/exports/ezra_nautilus.obj
ezra_nautilus/ezra_nautilus.blend

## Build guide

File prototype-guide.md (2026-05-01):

# Ezra — Investor Prototype Build Guide

**Goal:** Produce a credible sensory demonstration of the Ezra experience in 2–3 weeks for under $3,000, without manufacturing a production-ready device.

The investor prototype is not proof of manufacturing. It is proof of experience. The question investors need answered is: *does this interaction paradigm work?* Can I hold something, speak to it, feel it respond, and understand why someone would choose this over a phone? That question can be answered with a well-built prototype shell and a phone tethered in your pocket.

---

## Layer 1 — Physical Shell

**Goal:** An object investors can hold. Weight, texture, and material are the first sensory argument.

**Parts needed:**
- 1× KRION or Corian billet, approximately 120×75×20mm
- Access to a CNC shop (local fabricators, Xometry, Protolabs)
- Sandpaper: 220, 400, 800, 1200 grit
- Matte clear coat (optional)

**Process:**

1. Source KRION from a Porcelanosa distributor or Corian from a kitchen countertop fabricator. Small off-cut pieces are often available cheaply or free.

2. Provide the CNC shop with a basic 3D model (STEP file) defining:
   - The exterior golden-ratio river-stone profile, 108mm long, 66mm fuller tail, 63mm narrower head, 21mm crowned center thickness, 8mm edge thickness
   - Softened phone edges: large continuous radii, no flat exterior planes, and a crown high point shifted roughly 5mm rearward toward the palm side
   - A hollow interior cavity (wall thickness ~3–4mm, with thicker optical/thermal bosses where needed)
   - The 12mm circular sensor window recess on the lower face
   - A hidden centered rear Qi2/MagSafe-style coil and magnet envelope, not visible exterior ring geometry
   - A lower rear thermal contact zone
   - Thinned Corian/KRION or hidden light-pipe zones for a diffuse internal amber glow
   - Subtle tactile asymmetry: narrower head, fuller tail, flatter thumb sweep, rounder finger side, and a biased underside contact patch

3. After CNC milling, hand-sand exterior surfaces through grits to 1200. The finish should feel like a polished stone — not glossy, not rough. Matte is correct.

4. The shell does not need internals for the first investor meeting. The object in their hand is the argument. Approximate the correct weight with internal ballast (lead sheet, steel shot in epoxy) if needed.

**Cost:** $500–1,500 for CNC; $40–80 for material.  
**Time:** 1–2 weeks (including fabricator lead time).

---

## Layer 2 — Voice and Memory Demo

**Goal:** Demonstrate the voice interaction paradigm with plausible memory and context.

**Architecture:**

```
iPhone/Android (in pocket) → Bluetooth → Speaker in shell → User voice → Whisper API → Claude API → TTS → Speaker
```

This is a tethered demo. The phone does the compute. The shell contains only a speaker and a Bluetooth receiver (e.g., Adafruit Feather Bluefruit or similar). The user does not see the phone.

**Pre-load five demo scripts** into the Claude system prompt as memory context:

```
User's name: [name]
Recent meals: Nobu on Thursday (expense account), home-cooked salmon Friday
Recent stress events: Investor meeting prep, contract review with attorney
Upcoming: Flight to Austin on May 12, meeting with LP at 2pm
Contacts: Mom (Margaret), work partner (Alex)
```

Then demo these five interactions:

1. "Ezra, where did we eat last Thursday?"  
   → "You had dinner at Nobu on Thursday."

2. "What's my stress level been looking like?"  
   → "Your heart rate variability has been lower than your baseline for the past three days. The pattern usually correlates with high-pressure preparation periods. Do you want me to block your morning for a walk?"

3. "Remind me about the Austin flight."  
   → "You fly to Austin on May 12th. Your LP meeting is at 2pm. Should I set a departure reminder?"

4. "Is there anything from Mom?"  
   → "Margaret called at 9:47am. She didn't leave a message."

5. "Ezra, I need to think. Hold calls for an hour."  
   → "Done. I'll hold everything except Margaret and emergency contacts until 3:15."

**Cost:** Bluetooth receiver + speaker: $50–100. API costs: negligible.  
**Time:** 3–5 days for assembly and prompt engineering.

---

## Layer 3 — Haptic Demonstration

**Goal:** Show that the device communicates through touch in a meaningfully different way than a phone vibration.

**Parts:**
- 1× Lofelt L5 LRA (or Adafruit DRV2605L breakout + LRA motor)
- 1× Raspberry Pi Zero 2W or Arduino
- 1× small LiPo battery
- Jumper wire, foam tape

**Wire:** Pi Zero → DRV2605L driver (I2C) → LRA. Mount the LRA to the interior shell wall with foam tape on three sides (isolation prevents rattle).

**Program three patterns** to demonstrate via button trigger during the demo:

```python
# Pattern 1: Ambient notification (slow, soft)
AMBIENT = [(150, 0.3), (0, 0.2), (150, 0.3)]  # Hz, duration

# Pattern 2: Incoming call (double pulse, firmer)
CALL = [(200, 0.1), (0, 0.1), (200, 0.1), (0, 0.5)]

# Pattern 3: "Loved one" pattern (warm slow throb)
MOM = [(80, 0.8), (0, 0.4), (80, 0.8)]
```

Demo script: "Feel this — this is a standard notification. Now feel this — this is your mom. Notice the difference? The device is already communicating meaning before you consciously process it."

**Cost:** ~$100–150 for components.  
**Time:** 3–5 days for assembly and programming.

---

## Layer 4 — Warmth Demonstration (Optional but High-Impact)

**Parts:**
- 1× Peltier TEC1-12706 for benchtop demo, or thinner thermoelectric patch if available
- 1× copper heat spreader plate
- 1× Pi Zero 2W PWM GPIO → MOSFET → TEC
- 1× 5V 4A power supply (demo rig only)

**Wire:** Pi Zero GPIO → MOSFET gate → TEC+ (TEC− to power GND, copper plate on hot side).

**Demo:** Hand the shell to the investor. Trigger the warmth sequence from your phone via Bluetooth. The shell surface temperature rises 4–6°C in about 3 seconds. Say: "That's a message from your mom. You felt it before I told you what it was."

This is the most memorable 10 seconds in the demo. It activates a sensory channel no other consumer device uses for communication.

**Cost:** ~$30–50 for components.  
**Time:** 2–3 days.

---

## Full Demo Script (15 minutes)

1. **Hand them the shell (60 seconds).** Say nothing. Let them hold it. Let them notice the weight, the texture, the material. Most people will ask what it is.

2. **"It doesn't have a screen." (30 seconds).** Let that land. Answer the obvious question: "Yes, it makes calls. Yes, it knows your calendar. It does everything your phone does except show you a feed."

3. **Voice demo (5 minutes).** Run through the five interactions. Emphasize the memory: "It knows you."

4. **Haptic demo (2 minutes).** Pass it to them, run the patterns. Ask them to feel the difference between ambient, call, and loved one.

5. **Warmth (1 minute).** Trigger the Peltier. Let them experience it.

6. **The ask (remainder).** You have demonstrated that the experience paradigm is real, believable, and emotionally distinct from any existing product.

---

## Product Scene Storyboards

Use these as Onshape presentation scenes, render prompts, or investor demo beats:

| Scene | Product Behavior |
|---|---|
| Morning Guidance | User picks up Ezra from bedside. Soft glow. Ezra says recovery looks low and suggests a lighter day. |
| Pre-Meeting Calm | Device senses elevated pulse while held and suggests breathing cadence through slow haptics. |
| Evening Wind Down | Warm amber light, reduced stimulation, and a sleep-window recommendation after repeated poor sleep signals. |
| Walk Prompt | Subtle midday pulse after sedentary pattern detection; no screen, no shame loop. |
| Emotional Recovery | After an elevated stress episode, Ezra gives quiet guidance while the device remains warm and calm in the hand. |

These are non-diagnostic scenes. The claim is passive pattern intelligence and personal regulation, not medical assessment.

---

## What This Prototype Does Not Demonstrate

- Full PPG authentication and passive regulation sensing (this requires the sapphire window, MAX30102, security element, and longitudinal trend modeling — target for prototype v2)
- Cellular calling (tethered to phone; present as "demo mode")
- Production audio quality (directional microphone array)
- Battery life

These gaps are appropriate. Investors are funding the concept and the team, not the finished hardware. The prototype answers the question they need answered: *is this real?*

---

*Build guide current as of April 2026.*

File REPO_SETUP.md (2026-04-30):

# Ezra — Repository Metadata

## GitHub Repository Settings

**Name:** `ezra`  
**Description:** Screenless AI companion device. Voice, haptic, and thermal interface. Milled from mineral stone.  
**Website:** https://thegoodproject.net  
**Topics:** `hardware`, `voice-interface`, `screenless`, `haptic`, `iot`, `raspberry-pi`, `embedded`, `fido2`, `ppg`, `biometrics`, `ai`, `llm`

## License

This project is currently **proprietary / all rights reserved** during the specification and prototype phase.

A decision on open-source licensing (likely Apache 2.0 for firmware, proprietary for hardware design files) will be made prior to any public prototype release.

## Visibility

Set to **Private** until provisional patent filing is complete.

Make **Public** after:
1. Provisional patent filed (PPG authentication + screenless FIDO2 architecture)
2. First investor prototype complete
3. Legal review of IP disclosure implications

---

## Repo Structure (Final)

```
ezra/
├── README.md
├── SPEC.md
├── CONTRIBUTING.md
├── LICENSE
├── docs/
│   ├── philosophy.md
│   ├── prototype-guide.md
│   ├── ppg-authentication.md
│   └── fido2-integration.md
├── specs/
│   ├── hardware.md
│   ├── firmware.md
│   └── haptic-language.md
├── firmware/               ← (pending)
│   ├── services/
│   │   ├── voice_pipeline.py
│   │   ├── identity_service.py
│   │   ├── haptic_service.py
│   │   ├── thermal_service.py
│   │   ├── light_service.py
│   │   └── minion_context.py
│   ├── drivers/
│   │   ├── max30102.py
│   │   ├── drv2605l.py
│   │   └── quectel_ec25.py
│   ├── patterns/
│   │   └── haptic_library.json
│   └── requirements.txt
├── hardware/               ← (pending)
│   ├── kicad/
│   └── mechanical/
└── assets/
    ├── renders/
    └── diagrams/
```

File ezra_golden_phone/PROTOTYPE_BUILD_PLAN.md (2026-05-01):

# Ezra Prototype Build Plan

Source note captured from the Companion prototype BOM. Prices and vendors are planning estimates, not live procurement quotes.

## Current CAD Direction

- Blender remains the fast exterior-form tool for the skip-stone surface, glow, Corian material read, and hand-feel iteration.
- Onshape should become the engineering source once the exterior is frozen enough to package real components.
- The BOM below should drive the first Onshape internal-layout pass: battery, CM4 carrier, LTE module, sensor boards, LEDs, haptics, thermal module, antennas, USB-C, gasket logic, and service access.

## Onshape Translation Note

Create an `Ezra_Internal_Packaging_v1` Onshape assembly once the exterior shell is stable. Start with simplified bounding volumes before detailed parts:

- `Battery_Main_4000_Prototype`: largest central mass, single-cell LiPo placeholder.
- `PCB_CM4_IO_Carrier`: rectangular carrier for Raspberry Pi CM4 plus IO board.
- `Module_Coral_USB_TPU`: secondary compute block near CM4.
- `Module_LTE_EC21_MiniPCIe`: modem block with antenna keep-out along shell perimeter.
- `Sensor_PPG_MAX30102_Array`: underside biometric island aligned to shell contact zone.
- `Sensor_EDA_AD5940`: conductive contact interface near thumb/finger zones.
- `Sensor_Air_SEN55`: seam-integrated vent path and air chamber.
- `Light_Flood_XHP50`: thermal path, reflector/optic, and Corian diffusion zone.
- `Light_UVA_NCSU334A`: side-shielded aperture with visible-cut filter.
- `Haptic_LRA_Array`: multiple actuator zones for thumb, palm, edges, and utility cues.
- `Thermal_TEC_20x20`: palm warmth zone with graphite spreader and thermal isolation.
- `Power_USB_C_BQ25895`: bottom service/charge path with gasket.

Created Onshape entry points in document `Codex_Diagnostic_Test`:

| Element | Type | Element ID | Purpose |
|---|---|---|---|
| `Ezra_BOM_Packaging_Placeholders_v1` | Part Studio | `d1355228e9eb178ab2b6ecdc` | Placeholder geometry and imported/vendor reference parts. |
| `Ezra_Internal_Packaging_BOM_v1` | Assembly | `be2dc958b8a119b3730466be` | Internal packaging assembly driven by the BOM. |

## Onshape Off-The-Shelf CAD Search

The Onshape MCP can search public Onshape documents and inspect/export part studios. It does not currently expose a direct derive/insert/import-into-this-document command, so these are candidate source documents to open manually in Onshape or export/import through a follow-up workflow.

| BOM Item | Onshape Search Result | Document ID | Notes |
|---|---|---|---|
| Raspberry Pi CM4 | `Raspberry Pi CM4` | `ae9d25e0db89ab906fc1fc44` | Strong candidate. Contains `Raspberry-Pi-CM4` Part Studio and STEP blob. |
| Raspberry Pi CM4 IO Board | `Raspberry PI IO board` | `0256854bfb4471139c1d7c6e` | Strong candidate for prototype carrier envelope. |
| MAX30102 | `MAX30102.SLDPRT` | `2b6a382b6096799f0e36eca2` | Strong candidate for PPG module/package reference. |
| Quectel EC21 | `Quectel EC21-AUTL.step` | `4b3c55a5fd12cfabc2584409` | Strong candidate for LTE module. |
| Sensirion SEN55 | `Sensirion SEN55 SEN5x Duct - Mechanical_Design-In_Example_Truncated` | `6846ed48a47e5b526f6cd8d3` | Useful for airflow/ducting, not necessarily bare module. |
| DRV2605L | `DRV2605L` | `00c73188beed332d03150c4e` | Candidate haptic driver board/package. |
| 10 mm LRA coin motor | `10mm Coin Motor Vibration` | `65e9de9b05d13340af12d902` | Strong candidate for haptic actuator envelope. |
| MAX98357A | `MAX98357A` | `7c0c1710348a5cfc73e3e0b8` | Candidate I2S amp board/package. |
| Cree XHP50 | `LED's` | `0ab29e3e7fa40ed86d333bf0` | Weak candidate; verify package before use. |
| BQ25895 | `librem-5.step` | `a7a767c02eb208051f59750e` | Weak candidate; likely embedded in a phone assembly, not standalone eval board. |
| USB-C breakout | `pico` | `f6a1da4123fb6da728473368` | Weak candidate; use only if connector geometry is reusable. |
| 20x20 Peltier TEC | No good direct result | N/A | Use bounding box until vendor STEP is sourced. |
| LiPo 4000 mAh | No reliable direct result | N/A | Use actual supplier dimensions as bounding box. |

Recommendation: pull exact CAD for the high-confidence modules first: CM4, CM4 IO board, Quectel EC21, MAX30102, SEN55, LRA coin motor, and USB-C connector. Represent batteries, wires, gaskets, Corian shell clearances, and thermal pads as custom Onshape placeholders.

## Prototype Timeline

| Phase | Scope | Timing |
|---|---|---|
| 01 | Order demo-critical parts | This week |
| 02 | Board bring-up and shell fabrication | Weeks 2-3 |
| 03 | Software stack | Weeks 2-4 |
| 04 | Investor demo ready | Week 5 |

## BOM Summary

| Category | Component | Qty | Est. Price | Priority | CAD Packaging Notes |
|---|---:|---:|---:|---|---|
| Compute | Raspberry Pi CM4, 4GB RAM, 32GB eMMC, WiFi | 1 | $75 | P1 | Main processor volume. |
| Compute | CM4 IO Board / full breakout carrier | 1 | $30 | P1 | Prototype carrier, likely larger than production board. |
| Compute | Coral USB Accelerator / Edge TPU | 1 | $60 | P2 | Thermal and USB routing allowance. |
| Cellular | Quectel EC21 Mini PCIe LTE Cat-1 Module | 1 | $35 | P1 | Needs SIM access and RF keep-out. |
| Cellular | T-Mobile prepaid SIM, IoT/data/voice | 2 | $20 | P1 | Procurement item, no CAD except SIM slot. |
| Cellular | LTE adhesive flex antenna, 700-2700 MHz | 1 | $12 | P2 | Perimeter antenna zone clear of metal. |
| Biometric | MAX30102 breakout, PPG / SpO2 / HR | 2 | $20 | P1 | Underside optical window and light pipe. |
| Biometric | AD5940 eval board, EDA / stress | 1 | $85 | P2 | Conductive ring/contact routing. |
| Biometric | Bosch BMP390 breakout, pressure/temperature | 1 | $10 | P2 | Vent path to environment. |
| Biometric | Infineon SLB 9670 TPM 2.0 module | 1 | $18 | P2 | Secure element near main PCB. |
| Environmental | Sensirion SEN55, PM2.5 / VOC / temp / humidity | 1 | $45 | P2 | Airflow chamber and waterproof membrane path. |
| Environmental | ST VL53L5CX ToF 8x8 depth array | 1 | $15 | P3 | Hidden optical aperture if retained. |
| Haptic/Thermal | TI DRV2605L haptic driver breakout | 2 | $20 | P1 | Driver board near actuator harness. |
| Haptic/Thermal | 10 mm coin LRA haptic actuators | 4 | $16 | P1 | Thumb, palm, left edge, right edge zones. |
| Haptic/Thermal | 20x20 mm Peltier TEC element | 1 | $8 | P1 | Palm warmth zone with thermal spreader. |
| Haptic/Thermal | TI DRV8833 dual H-bridge breakout | 1 | $5 | P1 | TEC driver and heat/cool direction control. |
| Light/UV | Cree XHP50.3 COB LED, warm white / 5000K | 1 | $8 | P1 | Floodlight thermal path and diffuser zone. |
| Light/UV | Ledil ANGIE-S TIR optic | 1 | $6 | P2 | Directional torch optic volume. |
| Light/UV | TI TPS92515 LED driver eval board | 1 | $25 | P2 | Constant-current LED driver. |
| Light/UV | Nichia NCSU334A UV-A LED, 365 nm | 2 | $14 | P1 | Shielded side aperture and baffle. |
| Light/UV | 365 nm UV-pass visible-cut filter | 1 | $18 | P2 | Aperture/filter stack. |
| Light/UV | Tunable white LED pair, 1800K + 5500K | 1 | $12 | P3 | Circadian ambient light zone. |
| Voice | Knowles SPH0645LM4H MEMS microphone breakout | 2 | $20 | P1 | Hidden microphone pores and acoustic channels. |
| Voice | MAX98357A I2S amplifier breakout + speaker | 1 | $15 | P1 | Speaker cavity and acoustic slit. |
| Power | TI BQ25895 USB-C charger + power path eval board | 1 | $49 | P1 | Charger board, battery path, USB-C route. |
| Power | 4000 mAh 3.7 V single-cell LiPo battery | 1 | $30 | P1 | Largest internal component in prototype. |
| Power | USB-C breakout board, 5 V power + data | 1 | $8 | P2 | Bottom gasketed port. |
| Shell | Corian sheet, white/Arctic, 12 mm | 1 | $40 | P2 | Prototype shell stock. |
| Shell | CNC machining: shell body + sensor array drilling | 1 | $200 | P2 | Include extra shells for breakage. |
| IP | USPTO provisional filing fee | 1 | $320 | P1 | Legal/procurement item, not CAD. |

## Demo Critical Path

The demo-critical hardware is CM4 + carrier, LTE, PPG, haptics, thermal, primary light, microphone/speaker, power, and shell. Environmental sensing, depth sensing, and tunable ambient LEDs can remain additive until the main interaction loop works.

## Investor Demo Moments

| Moment | Behavior | Hardware Dependency |
|---|---|---|
| Hand authentication | PPG identifies owner in roughly 4 seconds. | MAX30102, TPM, software model |
| Mom reaches out | Warmth plus amber haptic pulse. | LTE, LRA, TEC, light channel |
| Voice + memory | Voice query answered from structured memory. | CM4, mic, speaker, LLM stack |
| UV sweep | Surface contamination fluoresces under UV-A. | UV-A LEDs, filter, baffle |
| Live call | Voice command places cellular/WhatsApp call. | LTE, Android stack, mic/speaker |

## Patent Note

Potential provisional-claim themes:

- Continuous passive PPG biometric authentication on a screenless handheld companion device.
- PPG-gated FIDO2/WebAuthn passkey signing.
- Live PPG session continuity that closes on loss of biometric contact.
- Presence-triggered PPG activation via proximity/depth sensing.
- PPG plus voice dual-factor authentication without screen, camera, or fingerprint surface.
- UV-A fluorescence inspection integrated into a screenless personal device.

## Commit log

2026-05-01 Add Ezra skip-stone design assets
    [ezra_golden_phone.blend]
2026-05-05 Update Ezra design progress package
    [ezra_nautilus.blend, ezra_nautilus.obj, ezra_nautilus.stl]
